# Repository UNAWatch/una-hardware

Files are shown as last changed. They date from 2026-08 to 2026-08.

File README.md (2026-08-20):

## Summary

This repo contains the hardware design files for UNA watch, enabling users to debug their own hardware. 

## Contents

una-watch

	- electronics
	
		Schematic, assembly and fabrication drawings for each of the 6 PCBs in UNA Watch:
	
		UNAaltimeter_MS5837
		UNAbody_PAH8316
		UNAcore
		UNAlink_AG3335M
		UNAlink_BLUENRG2
		UNAview_LS012
	
	- mechanical
	
		.stp files for each mechanical part

## License

The designs and related documentation
in this repository are licensed under the Creative Commons Attribution
4.0 International License (CC BY 4.0), unless otherwise noted.

You are free to use, reproduce, modify, manufacture from, and redistribute
these materials, provided appropriate attribution is given.

See the LICENSE file for details.

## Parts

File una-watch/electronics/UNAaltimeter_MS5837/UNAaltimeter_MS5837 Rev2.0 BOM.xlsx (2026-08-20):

Bill of Materials |  |  |  |  |  |  |  | Una Watch Ltd
PCB | UNAaltimeter_MS5837
BOM Revision | 2
Date | 2025-08-08
Author Email | lewis@unawatch.com
Item Number | Quantity | Value | Part Reference | Part_Number | Manufacturer | ManuPart | Description | PCB Footprint
1 | 1 | 470nF_6.3V | C5 | 001-0005 | Murata | GRM033R60J474KE90D | Cap ceramic,X5R,470nF,10%,6.3V,C0201 | C0201
2 | 1 | BM23PF0.8-10DP-0.35V51 | J1 | 200-0034 | Hirose | BM23PF0.8-10DP-0.35V51 | 10 position connector, plug, 0.35mm pitch, 0.3A signal contact, 5A power contact, 0.8mm stack height | HRS_BM23PF08-10DP-035V51
3 | 1 | MS583702BA01-50 | U3 | 103-0012 | TE | MS583702BA01-50 | Pressure and Temperature Sensor, Gel-filled | XDCR_MS583702BA01-50

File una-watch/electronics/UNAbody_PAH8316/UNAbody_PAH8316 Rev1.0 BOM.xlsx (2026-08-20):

Bill of Materials |  |  |  |  |  |  |  | Una Watch Ltd
PCB | UNAbody_PAH8316
BOM Revision | 1
Date | 2025-04-10
Author Email | lewis@unawatch.com
Item Number | Quantity | Value | Part Reference | Part_Number | Manufacturer | ManuPart | Description | PCB Footprint
1 | 6 | 1uF_10V | C1 C5 C10 C11 C13 C14 | 000-0003 | Murata | GRM155Z71A105KE01D | Cap ceramic,X7R,1uF,10%,10V,C0402 | C0402
2 | 6 | 100nF | C2 C3 C4 C6 C7 C12 | 001-0001 | Murata | GRM033R61A104KE15D | Cap ceramic,X5R,100nF,10%,10V,C0201 | C0201
3 | 2 | 22uF_10V | C8 C9 | 000-0002 | Murata | GRM158R61A226ME15D | Cap ceramic,X5R,22uF,20%,10V,C0402 | C0402
4 | 1 | 47nF | C15 | 001-0010 | Murata | GRM033R61C473KE84D | Cap ceramic,X5R,47nF,10%,16V,C0201 | C0201
5 | 4 | SFH_2703 | D1 D3 D4 D6 | 206-0005 | AMS OSRAM | SFH 2703 | Silicon PIN Photodiode, 0.95V Forward Voltage | C0603
6 | 2 | SFH_7016 | D2 D5 | 206-0006 | AMS OSRAM | SFH 7016 | Green, Red and Infrared LED, 1.85 x 1.65 package | C0603
7 | 1 | 330K_0201 | R1 | 011-0012 | Yageo | RC0201FR-07330KL | Resistor 330K 1% 0201 | R0201
8 | 1 | 82K_0201 | R2 | 011-0013 | Yageo | RC0201FR-0782KL | Resistor 82K 1% 0201 | R0201
9 | 34 | TP_1.0mm | TP1 TP2 TP3 TP4 TP5 TP6 TP7 TP8 TP9 TP10 TP11 TP12 TP13 TP14 TP15 TP16 TP17 TP18 TP19 TP20 TP21 TP22 TP23 TP24 TP25 TP26 TP27 TP28 TP29 TP30 TP31 TP32 TP33 TP34 | 202-0000 | N/A | N/A | NOPOP - SMT Test Point Circular 1.0 mm dia | TP_1-0mm_dia_SMT
10 | 1 | PAH8316LS-IN | U1 | 103-0010 | Pixart | PAH8316LS-IN | PPG AFE for HRD and SP02, 6 LED drivers, 4 Photodiode inputs, IR touch detection, DC Lead On/Off Detection
11 | 1 | NCP110AFCT180T2G | U2 | 101-0007 | OnSemi | NCP110AFCT180T2G | 1.8V Output LDO in WLCSP4 package, Input 1.1-5.5V, 200mA, PSRR: 95 dB,
12 | 1 | N24S64BC4DYT3G | U3 | 102-0002 | OnSemi | N24S64BC4DYT3G | EEPROM, 64Kb, I2C, CSP | BGA4C40P2X2_74X84X30
13 | 1 | NCP705MTADJTCG | U4 | 101-0009 | OnSemi | NCP705MTADJTCG | Adjustable Output LDO in WDFN5 package, Input 2.5-5.5V, 500mA, PSRR: 71 dB

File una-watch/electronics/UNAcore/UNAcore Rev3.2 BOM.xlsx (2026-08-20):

Bill of Materials |  |  |  |  |  |  |  | Una Watch Ltd
PCB | UNAcore
BOM Revision | 3.2
Date | 2026-05-05
Author Email | lewis@unawatch.com
Item Number | Quantity | Value | Part Reference | Part_Number | Manufacturer | ManuPart | Description | PCB Footprint
1 | 4 | 10uF_6.3V | C1 C13 C55 C57 | 000-0001 | Murata | GRM155R60J106ME15D | Cap ceramic,X5R,10uF,20%,6.3V,C0402 | C0402
2 | 27 | 100nF | C2 C3 C4 C5 C6 C7 C8 C9 C10 C11 C14 C16 C20 C21 C22 C23 C35 C36 C39 C40 C43 C44 C53 C62 C63 C80 C81 | 001-0001 | Murata | GRM033R61A104KE15D | Cap ceramic,X5R,100nF,10%,10V,C0201 | C0201
3 | 10 | 4.7uF_10V | C12 C37 C38 C48 C49 C50 C51 C58 C60 C66 | 000-0000 | TDK | C1005X5R1A475K050BC | Cap ceramic,X5R,4.7uF,10%,10V,C0402 | C0402
4 | 18 | 1.0uF_10V | C15 C17 C41 C42 C46 C54 C59 C71 C72 C73 C74 C76 C77 C78 C79 C84 C85 C87 | 001-0000 | Murata | GRM033R61A105ME15D | Cap ceramic,1.0uF,20%,10V,C0201 | C0201
5 | 5 | 2.2uF_10V | C18 C19 C45 C47 C89 | 001-0002 | Murata | GRM033R61A225KE47D | Cap ceramic,2.2uF,10%,10V,C0201 | C0201
6 | 2 | 470nF_6.3V | C52 C56 | 001-0005 | Murata | GRM033R60J474KE90D | Cap ceramic,X5R,470nF,10%,6.3V,C0201 | C0201
7 | 1 | 4.7nF | C61 | 001-0006 | Murata | GRM033R61A472KA01D | Cap ceramic,X5R, 4.7nF,10%,10V,C0201 | C0201
8 | 2 | 22uF_10V | C67 C68 | 000-0002 | Murata | GRM158R61A226ME15D | Cap ceramic,X5R,22uF,20%,10V,C0402 | C0402
9 | 2 | 8pF | C69 C70 | 001-0013 | Murata | GRM0335C1H8R0CA01D | Cap ceramic,C0G/NP0,8pF,+-0.25pF,50V,C0201 | C0201
10 | 1 | 2.2uF_50V_0603 | C86 | 002-0006 | Murata | GRM188R61H225KE11D | Cap ceramic,X5R, 2.2uF, 10%, 50V, C0603 | C0603
11 | 6 | RCLAMP2261ZA.F | D1 D2 D3 D4 D6 D7 | 206-0012 | Semtech | RCLAMP2261ZA.F | Bidirectional TVS ESD protection diode, 0201 package, 22V Working, 10.5V Clamp, 24V Breakdown, 30kV ESD | DIO_RCLAMP2261ZAF
12 | 1 | ESDA25P35-1U1M | D5 | 206-0011 | ST | ESDA25P35-1U1M | Unidirectional TVS ESD protection diode, 0603 package, 22V Working, 41V Clamp, 23.3V Breakdown, 30kV ESD | TVS_ESDA25P35-1U1M
13 | 2 | BM23PF0.8-24DS-0.35V51 | J1 J2 | 200-0027 | Hirose | BM23PF0.8-24DS-0.35V51 | 24 position connector, socket, 0.35mm pitch, 0.3A signal contact, 5A power contact, 0.8mm stack height | HRS_BM23PF08-24DS-035V51
14 | 1 | DF37NC1.5-30DS-0.4V | J3 | 200-0029 | Hirose | DF37NC1.5-30DS-0.4V | 30 position connector, receptacle, 0.4mm pitch, 0.3A current rating, 1.5mm stack height | HRS_DF37NC15-30DS-04V51
15 | 2 | A123803NXXSV072X01 | J4 J5 | 200-0016 | Tsingre | A123803NXXSV072X01 | Custom pogo pin connector, 8 pin, through-hole, 1.27mm pitch, 2 rows of 4 | TSINGRE_A123803NXXSV072X01
16 | 1 | CX90MWD2G-24P | J6 | 200-0028 | Hirose | CX90MWD2G-24P | USB Type-C connector, USB 3.1 Gen 2, 24 contact, mid mount, IPX8 | HIROSE_CX90MWD2G-24P
17 | 2 | SCTA4A0100 | J7 J8 | 200-0017 | Alps | SCTA4A0100 | Spring Contact, 1.4 x 1.4mm, 1.8m height uncompressed, 1.2-1.6mm compressed | ALPS_SCTA1A0100
18 | 1 | 9155002541006 | J9 | 200-0032 | Kyocera AVX | 9155002541006 | 2 Position Spring Battery Contact Connector Surface Mount, Right Angle | avx_9155002541006
19 | 1 | BM23PF0.8-10DS-0.35V51 | J10 | 200-0033 | Hirose | BM23PF0.8-10DS-0.35V51 | 10 position connector, socket, 0.35mm pitch, 0.3A signal contact, 5A power contact, 0.8mm stack height | HRS_BM23PF08-10DS-035V51
20 | 1 | M50-3630242 | J11 | 200-0031 | Harwin | M50-3630242 | 2 position header, pin strip, 1.27mm pitch, 3mm mating post length, SMT | HARWIN_M50-3630242
21 | 1 | una_shield_v2 | J12 | 203-0001 | Shenzhen Welin | una_shield_v2 | EMI shield for Una PCB V2 | una_shield_v2
22 | 3 | 2.2uH_750mA | L1 L2 L3 | 020-0000 | Murata | LQM18PN2R2MFR | Power Inductor 2.2uH, 375mOhm, 20%, Irating = 750mA,1.6 x 0.8 x 0.8mm | L0603
23 | 1 | 1uH_1.8A | L5 | 020-0001 | Murata | DFE18SBN1R0ME0L | Power Inductor 1uH, 120mOhm, 20%, Irating = 1.8A,1.6 x 0.8 x 0.8mm | L0603
24 | 1 | VZ30C1T8219732L | M1 | 205-0001 | Vybronics | VYBRONICS_VZ30C1T8219732L | Vibration ERM motor, 2.7V DC, 3.4mm Height | VYBRONICS_VZ30C1T8219732L
25 | 8 | 3K3_0201 | R1 R2 R3 R4 R5 R6 R7 R8 | 011-0002 | Yageo | RC0201FR-073K3L | Resistor 3K3 1% 0201 | R0201
26 | 2 | 10K_0201 | R9 R11 | 011-0000 | Yageo | RC0201JR-0710KL | Resistor 10K 5% 0201 | R0201
27 | 4 | 100K_0201 | R12 R13 R31 R37 | 011-0003 | Yageo | RC0201JR-07100KL | Resistor 100K 5% 0201 | R0201
28 | 7 | NOPOP | R24 R25 R27 R28 R29 R30 R39 | 011-0008 | NA | NA | Resistor NOPOP 0201 | R0201
29 | 1 | 0R0_0201 | R26 | 011-0005 | Yageo | RC0201FR-070RL | Resistor 0R0 1% 0201 | R0201
30 | 1 | 22K_0201 | R32 | 011-0016 | Yageo | RC0201FR-0722KL | Resistor 22K 1% 0201 | R0201
31 | 2 | 1K_0201 | R33 R34 | 011-0001 | Yageo | RC0201JR-071KL | Resistor 1K 5% 0201 | R0201
32 | 1 | 200R_0201 | R40 | 011-0009 | Yageo | RC0201FR-07200RL | Resistor 200R 1% 0201 | R0201
33 | 4 | EVPAEBB2A | SW1 SW2 SW3 SW4 | 201-0000 | Panasonic | EVPAEBB2A | Tactile switch, Edge-Mounted, Side Operated, 1.6N, 4.5 x 2.2mm | PANASONIC_EVPAEBB2A
34 | 36 | TP_1.0mm_dia_SMT | TP1 TP2 TP3 TP4 TP5 TP6 TP7 TP8 TP9 TP10 TP11 TP13 TP14 TP15 TP16 TP17 TP18 TP19 TP20 TP21 TP22 TP23 TP24 TP25 TP26 TP27 TP28 TP29 TP30 TP31 TP32 TP33 TP34 TP35 TP36 TP37 | 202-0000 | N/A | N/A | NOPOP - SMT Test Point Circular 1.0 mm dia | TP_1-0mm_dia_SMT
35 | 1 | STM32U5A5QJI6Q | U1 | 100-0003 | ST | STM32U5A5QJI6Q | 32-bit microcontroller, Cortex-M33, 160 MHz, 4MB Flash, 2.5MB RAM, with SMPS, UFBGA132 package, Hw Encryption | UFBGA132_7X7_STM
36 | 1 | SiT1532AC-J5-D14-32.768 | U2 | 106-0000 | SiTime | SiT1532AC-J5-D14-32.768 | 32.768 KHz mems oscillator, 75ppm, -10C to 70C | sit_csp4
37 | 2 | NCP335FCT2G | U3 U4 | 101-0006 | NXP | NCP335FCT2G | Load switch, 2A, WLCSP4 package | NCP334-D
38 | 1 | EMMC04G-CT32-01G10 | U5 | 102-0000 | Kingston | EMMC04G-CT32-01G10 | 4GB eMMC, Jedec eMMC 5.1 compliant, Ultra-small 7.5x9.0x0.8 | emmc_vfbfa153_7_5x9
39 | 1 | DRV2625YFF | U6 | 111-0000 | TI | DRV2625YFFR | Haptic driver for ERM/LRA with preloaded waveform data | BGA9C40P3X3_147X133X62
40 | 1 | PAM8904EGPR | U7 | 112-0000 | Diodes | PAM8904EGPR | Piezo sounder driver with charge pump boost converter | diodes_wqfn202012
41 | 1 | PCA9420UKZ | U8 | 101-0001 | NXP | PCA9420UKZ | PMIC with bat charger, 2 bucks, 2 LDOs | nxp_wlcsp25
42 | 1 | MAX17262REWL+ | U9 | 101-0002 | Maxim | MAX17262REWL+ | Battery Power Gauge IC, I2C Interface, Internal Current Sense Resistor | maxim_wlp9
43 | 1 | 74LVC1T45FW4-7 | U10 | 104-0000 | Diodes | 74LVC1T45FW4-7 | 1-bit level translator, direction control | di_x2-df1010-6
44 | 1 | TPS61299YBHR | U13 | 101-0003 | TI | TPS61299YBHR | Synchronous Boost Converter, Input 0.7-5.5V, Output 1.8-5.5V, WCSP package, Fast Transient Response | BGA6N40P3X2_122X88X62N
45 | 1 | AP7350D-30CF4-7 | U16 | 101-0008 | Diodes | AP7350D-30CF4-7 | Fixed 3.0V Output LDO in 4-XFBGA package, Input 2-5.25V, 150mA, 0.4uA quiescent current, with enable pin | AP7350D30CF47
46 | 1 | TXS0102DQMR | U17 | 104-0004 | TI | TXS0102DQMR | 2-bit level translator, bi-directional, open-drain and push-pull, X2SON package | IC_TXS0102DQMR
47 | 1 | STUSB4500LBJR | U18 | 104-0014 | ST | STUSB4500LBJR | USB Type-C Sink Port Controller, 5V Only | BGA25N40P5X5_259X259X54N
48 | 1 | STL4P3LLH6 | U19 | 113-0001 | ST | STL4P3LLH6 | P-channel MOSFET, -30V, -4A, RON=0.056, 2.4W, PowerFLAT 2x2 | STL4P3LLH6
49 | 2 | NX20P0407UKZ | U21 U22 | 104-0016 | NXP | NX20P0407UKZ | USB Type-C CC and SBU Protection with SBU Enable Pin | BGA12N40P3X4_127X167X56
50 | 1 | TPS7A0233PYCHR | U23 | 101-0013 | TI | TPS7A0233PYCHR | 3.3V Output LDO in DSBGA-4 package, Input 1.5V to 6.0V, 310mV dropout voltage, 200mA Output Current, 25nA Queiscent | BGA4C35P2X2_64X64X40
51 | 1 | Xtal_16Mhz | X1 | 105-0002 | ECS | ECS-160-8-37-CWY-TR3 | 16 MHz smd xtal, 15ppm, 8pF, 2mmx1.6mm, -30C to 85C | xtal_4pin_2x1p6

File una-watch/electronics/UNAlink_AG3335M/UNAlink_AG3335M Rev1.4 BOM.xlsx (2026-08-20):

Bill of Materials |  |  |  |  |  |  |  | Una Watch Ltd
PCB | UNAlink_AG3335M
BOM Revision | 1.4
Date | 2026-05-05
Author Email | lewis@unawatch.com
Item Number | Quantity | Value | Part Reference | Part_Number | Manufacturer | ManuPart | Description | PCB Footprint
1 | 8 | 100nF | C1 C8 C32 C36 C37 C38 C39 C40 | 001-0001 | Murata | GRM033R61A104KE15D | Cap ceramic,X5R,100nF,10%,10V,C0201 | C0201
2 | 7 | 2.2uF_10V | C2 C7 C18 C41 C43 C44 C45 | 001-0002 | Murata | GRM033R61A225KE47D | Cap ceramic,2.2uF,10%,10V,C0201 | C0201
3 | 14 | 1.0uF_10V | C3 C4 C6 C9 C10 C12 C13 C14 C20 C23 C24 C25 C26 C27 | 001-0000 | Murata | GRM033R61A105ME15D | Cap ceramic,1.0uF,20%,10V,C0201 | C0201
4 | 2 | 4.7uF_10V | C5 C21 | 000-0000 | TDK | C1005X5R1A475K050BC | Cap ceramic,X5R,4.7uF,10%,10V,C0402 | C0402
5 | 2 | 6pF | C19 C22 | 001-0012 | Murata | GRM0335C1H6R0CA01D | Cap ceramic,C0G/NP0,6pF,+-0.25pF,50V,C0201 | C0201
6 | 7 | 47pF | C28 C29 C30 C31 C33 C34 C35 | 001-0011 | Murata | GRM0335C1E470FA01D | Cap ceramic,C0G/NP0,47pF,1%,25V,C0201 | C0201
7 | 1 | 33pF | C42 | 001-0014 | Murata | GRM0335C1E330FA01D | Cap ceramic,C0G/NP0,33pF,1%,25V,C0201 | C0201
8 | 1 | NOPOP | D1 | 206-0013 | N/A | N/A | NOPOP - SP1005 Series | DIODFN60X30X33-2N
9 | 1 | SAFFB1G56KB0F0A | FL1 | 109-0000 | Murata | SAFFB1G56KB0F0A | GPS L1 Saw Filter | FIL_B39162B9417K610
10 | 1 | SAWFD1G17AA0F0A | FL2 | 109-0002 | Murata | SAWFD1G17AA0F0A | GPS L1 and L5 Saw Filter, 1 In, 2 Out | DS-SAWFD1G17AA0F0A
11 | 1 | SAFFB1G17AA0F0A | FL3 | 109-0001 | Murata | SAFFB1G17AA0F0A | GPS L5 Saw Filter | FIL_B39162B9417K610
12 | 1 | MP10363 | G1 | 106-0002 | Golledge | MP10363 | 26.0MHz GTXO-203T/ES SM TCXO 1.8V TCXO no VC, ±0.5ppm, -30+85°C 1.8V Supply | NT2016_SMALL
13 | 1 | BM23PF0.8-24DP-0.35V51 | J1 | 200-0026 | Hirose | BM23PF0.8-24DP-0.35V51 | 24 position connector, plug, 0.35mm pitch, 0.3A signal contact, 5A power contact, 0.8mm stack height | HRS_BM23PF08-24DP-035V51
14 | 3 | 3100069 | J2 J3 J4 | 200-0001 | TE | 3100069 | Spring Contact, 2.7 x 1.5mm, 1.7mm height uncompressed, 1.5A current | TE_3100069
15 | 1 | 8.2nH | L1 | 022-0006 | MURATA | LQP03HQ8N2H02D | RF Inductor, 8.2nH, 400mOhms, 3%, Irating = 300mA, 0201 | L0201
16 | 1 | NOPOP_0201 | L2 | 022-0011 | NA | NA | Inductor NOPOP 0201 | L0201
17 | 2 | 9.1nH | L3 L4 | 022-0005 | MURATA | LQP03HQ9N1H02D | RF Inductor, 9.1nH, 400mOhms, 3%, Irating = 300mA, 0201 | L0201
18 | 1 | 10nH | L5 | 022-0007 | MURATA | LQP03HQ10NH02D | RF Inductor, 10nH, 400mOhms, 3%, Irating = 300mA, 0201 | L0201
19 | 1 | 6.8nH | L6 | 022-0008 | MURATA | LQP03HQ6N8H02D | RF Inductor, 6.8nH, 400mOhms, 3%, Irating = 300mA, 0201 | L0201
20 | 1 | 6.2nH | L7 | 022-0009 | MURATA | LQP03HQ6N2H02D | RF Inductor, 6.2nH, 250mOhms, 3%, Irating = 400mA, 0201 | L0201
21 | 1 | 7.5nH | L8 | 022-0010 | MURATA | LQP03HQ7N5H02D | RF Inductor, 7.5nH, 300mOhms, 3%, Irating = 400mA, 0201 | L0201
22 | 1 | 4nH | L9 | 022-0004 | MURATA | LQP03TN4N0B02D | RF Inductor, 4nH, 400mOhms, 0.1nH, Irating = 350mA, 0201 | L0201
23 | 1 | 1nF | R3 | 001-0009 | Murata | GRM0335C1E102FA01D | Cap ceramic,C0G/NP0,1nF,1%,25V,C0201 | C0201
24 | 1 | 100K_0201 | R4 | 011-0003 | Yageo | RC0201JR-07100KL | Resistor 100K 5% 0201 | R0201
25 | 8 | NOPOP | R6 R7 R8 R10 R11 R13 R18 R19 | 011-0008 | NA | NA | Resistor NOPOP 0201 | R0201
26 | 3 | 0R0_0201 | R9 R16 R17 | 011-0005 | Yageo | RC0201FR-070RL | Resistor 0R0 1% 0201 | R0201
27 | 1 | 1K_0201 | R12 | 011-0001 | Yageo | RC0201JR-071KL | Resistor 1K 5% 0201 | R0201
28 | 1 | 33K_0201 | R14 | 011-0015 | Yageo | RC0201FR-0733KL | Resistor 33K 1% 0201 | R0201
29 | 1 | 82K_0201 | R15 | 011-0013 | Yageo | RC0201FR-0782KL | Resistor 82K 1% 0201 | R0201
30 | 7 | TP_1.0mm | TP6 TP7 TP8 TP9 TP11 TP12 TP16 | 202-0000 | N/A | N/A | NOPOP - SMT Test Point Circular 1.0 mm dia | TP_1-0mm_dia_SMT
31 | 1 | GND_PAD | TP15 | 208-0000 | N/A | N/A | Exposed ground pad for UNAlink | gnd_pad_x20_6_y2_5
32 | 1 | N24S64BC4DYT3G | U1 | 102-0002 | OnSemi | N24S64BC4DYT3G | EEPROM, 64Kb, I2C, CSP | BGA4C40P2X2_74X84X30
33 | 1 | AG3335MV/B | U2 | 103-0008 | Airoha | AG3335MV/B | Dual Frequency L1 L5 GNSS Receiver | AG3335M
34 | 1 | NCP335FCT2G | U3 | 101-0006 | NXP | NCP335FCT2G | Load switch, 2A, WLCSP4 package | NCP334-D
35 | 1 | BGA524N6 | U5 | 112-0001 | Infineon | BGA524N6E6327XTSA1 | GNSS L1 band low noise amplifier, 19.6 dB gain, 0.55 dB NF | PSON35P110X70X35-6N
36 | 1 | BGA855N6 | U6 | 112-0002 | Infineon | BGA855N6E6327XTSA1 | GNSS L2/L5 band low noise amplifier, 17.8 dB gain, 0.6 dB NF | PSON35P110X70X35-6N
37 | 1 | BMI270 | U7 | 103-0009 | Bosch | BMI270 | IMU 3D accelerometer, 3D gyroscope, SPI and I2C | ST_LGA-14
38 | 1 | BMM350 | U8 | 103-0011 | Bosch | BMM350 | 3-Axis Magnetic Sensor, I2C | BMM350
39 | 1 | LD57100JR | U9 | 101-0011 | ST | LD57100JR | Adjustable Output LDO, Vout = 0.5 to 3.0V, Vin = Vout + 40mV, Flipchip 6 package | BGA6C40P2X3_78X118X36
40 | 1 | ECS-.327-6-16R-TR | X1 | 105-0001 | ECS | ECS-.327-6-16R-TR | 32.768 KHz smd xtal, 20ppm, 6pF, 60kOhm ESR, 1.6mmx1.0mm, -40C to 85C | ECX-16R

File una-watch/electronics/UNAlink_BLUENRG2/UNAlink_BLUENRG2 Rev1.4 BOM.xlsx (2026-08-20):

Bill of Materials |  |  |  |  |  |  |  | Una Watch Ltd
PCB | UNAlink_BLUENRG2
BOM Revision | 1.4
Date | 2026-02-05
Author Email | lewis@unawatch.com
Item Number | Quantity | Value | Part Reference | Part_Number | Manufacturer | ManuPart | Description | PCB Footprint
1 | 3 | 1.0uF_10V | C1 C3 C11 | 001-0000 | Murata | GRM033R61A105ME15D | Cap ceramic,1.0uF,20%,10V,C0201 | C0201
2 | 6 | 100nF | C2 C4 C5 C7 C10 C12 | 001-0001 | Murata | GRM033R61A104KE15D | Cap ceramic,X5R,100nF,10%,10V,C0201 | C0201
3 | 1 | 150pF | C6 | 001-0003 | Murata | GRM033R71C151KA01D | Cap ceramic,X7R,150pF,10%,16V,C0201 | C0201
4 | 2 | 12pF | C8 C9 | 001-0004 | Murata | GRM0335C1H120GA01D | Cap ceramic,C0G/NP0,12pF,2%,50V,C0201 | C0201
5 | 1 | BM23PF0.8-24DP-0.35V51 | J1 | 200-0026 | Hirose | BM23PF0.8-24DP-0.35V51 | 24 position connector, plug, 0.35mm pitch, 0.3A signal contact, 5A power contact, 0.8mm stack height | HRS_BM23PF08-24DP-035V51
6 | 2 | 3100069 | J2 J3 | 200-0001 | TE | 3100069 | Spring Contact, 2.7 x 1.5mm, 1.7mm height uncompressed, 1.5A current | TE_3100069
7 | 2 | 10K_0201 | R1 R5 | 011-0000 | Yageo | RC0201JR-0710KL | Resistor 10K 5% 0201 | R0201
8 | 2 | 1K_0201 | R2 R3 | 011-0001 | Yageo | RC0201JR-071KL | Resistor 1K 5% 0201 | R0201
9 | 2 | NOPOP_0201 | R4 R6 | 011-0008 | NA | NA | Resistor NOPOP 0201 | R0201
10 | 2 | 0R0_0201 | R7 R8 | 011-0005 | Yageo | RC0201FR-070RL | Resistor 0R0 1% 0201 | R0201
11 | 8 | TP_1.0mm | TP1 TP2 TP3 TP4 TP8 TP9 TP10 TP13 | 202-0000 | N/A | N/A | NOPOP - SMT Test Point Circular 1.0 mm dia | TP_1-0mm_dia_SMT
12 | 1 | GND_PAD | TP14 | 208-0000 | N/A | N/A | Exposed ground pad for UNAlink | gnd_pad_x20_6_y2_5
13 | 1 | BlueNRG-234N | U1 | 100-0001 | ST | BlueNRG-234N | Bluetooth low energy network coprocessor, BLE 5.0 compliant | ST_WLCSP34
14 | 1 | BALF-NRG-02D3 | U2 | 107-0000 | ST | BALF-NRG-02D3 | Matching network and harmonic filter for ST BlueNRG | ST_WLCSP4
15 | 1 | N24S64BC4DYT3G | U3 | 102-0002 | OnSemi | N24S64BC4DYT3G | EEPROM, 64Kb, I2C, CSP | BGA4C40P2X2_74X84X30
16 | 1 | Xtal_32Mhz | X1 | 105-0000 | Murata | XRCGB32M000F2P00R0 | 32 MHz smd xtal, 20ppm, 6pF, 2mmx1.6mm, -30C to 85C | xtal_4pin_2x1p6

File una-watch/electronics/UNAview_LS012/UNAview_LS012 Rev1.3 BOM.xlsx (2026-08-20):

Bill of Materials |  |  |  |  |  |  |  | Una Watch Ltd
PCB | UNAview_LS012
BOM Revision | 1.3
Date | 2025-04-09
Author Email | lewis@unawatch.com
Item Number | Quantity | Value | Part Reference | Part_Number | Manufacturer | ManuPart | Description | PCB Footprint
1 | 7 | 100nF | C1 C2 C3 C5 C6 C7 C8 | 001-0001 | Murata | GRM033R61A104KE15D | Cap ceramic,X5R,100nF,10%,10V,C0201 | C0201
2 | 3 | 1.0uF_10V | C4 C9 C10 | 001-0000 | Murata | GRM033R61A105ME15D | Cap ceramic,1.0uF,20%,10V,C0201 | C0201
3 | 1 | DF37C-30DP-0.4V | J1 | 200-0030 | Hirose | DF37C-30DP-0.4V | 30 position connector, plug, 0.4mm pitch, 0.3A current rating, 1.5mm stack height | HRS_DF37C-30DP-04V51_l3
4 | 1 | 503566-2102 | J2 | 200-0000 | Molex | 503566-2102 | 0.30mm Pitch Easy-On FPC Connector, 0.95mm Height, Right Angle, Surface Mount, Bottom Contact Style, 21 Circuits | MOLEX_5035662102
5 | 1 | 503480-0400 | J3 | 200-0020 | Molex | 503480-0400 | 0.50mm Pitch Easy-On BackFlip Type FPC Connector, 1.00mm Height, Right Angle, Surface Mount, Dual Contact Style, 4 Circuits | MOLEX_503480-0400
6 | 1 | NTK3139PT1G | Q1 | 113-0000 | On Semi | NTK3139PT1G | P-channel MOSFET, -20V, -780mA, RON=0.38, 310mW, SOT723 | ONSEMI_SOT723
7 | 1 | 10K_0201 | R1 | 011-0000 | Yageo | RC0201JR-0710KL | Resistor 10K 5% 0201 | R0201
8 | 1 | 82R_0201 | R2 | 011-0010 | Yageo | RC0201FR-0782RL | Resistor 82R 1% 0201 | R0201
9 | 17 | TP_1.0mm_dia_SMT | TP1 TP2 TP3 TP4 TP5 TP6 TP7 TP8 TP9 TP10 TP11 TP12 TP13 TP14 TP15 TP16 TP17 | 202-0000 | N/A | N/A | NOPOP - SMT Test Point Circular 1.0 mm dia | TP_1-0mm_dia_SMT
10 | 2 | TXB0108YZPR | U1 U2 | 104-0001 | TI | TXB0108YZPR | 8-bit level translator, auto-direction sensing, bi-directional, push-pull, DSBGA package | BGA20N50P4X5_188X238X50
11 | 1 | N24S64BC4DYT3G | U4 | 102-0002 | OnSemi | N24S64BC4DYT3G | EEPROM, 64Kb, I2C, CSP | BGA4C40P2X2_74X84X30

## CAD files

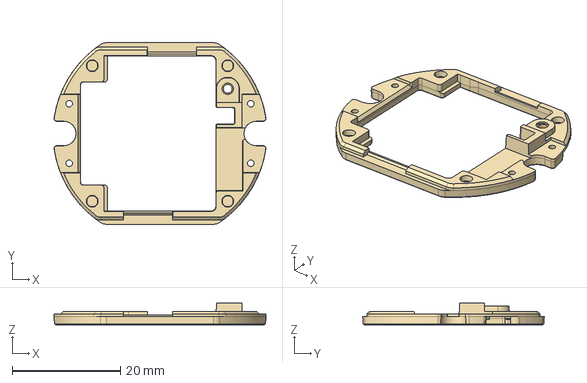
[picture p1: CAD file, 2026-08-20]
una-watch/mechanical/Battery_Compartment_501-0018_Rev-2.stp
39.1 x 33.5 x 4.00 mm

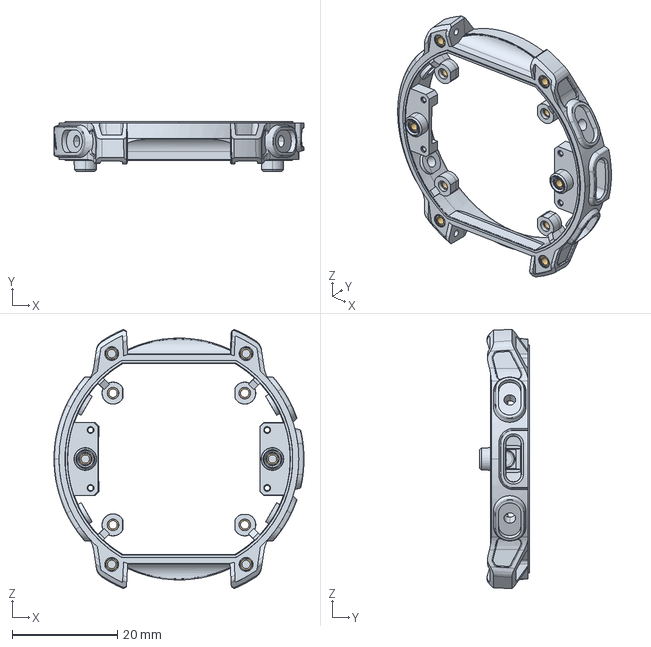
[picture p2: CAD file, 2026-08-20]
una-watch/mechanical/Housing_501-0015_Rev-2.stp
47.4 x 9.40 x 49.2 mm

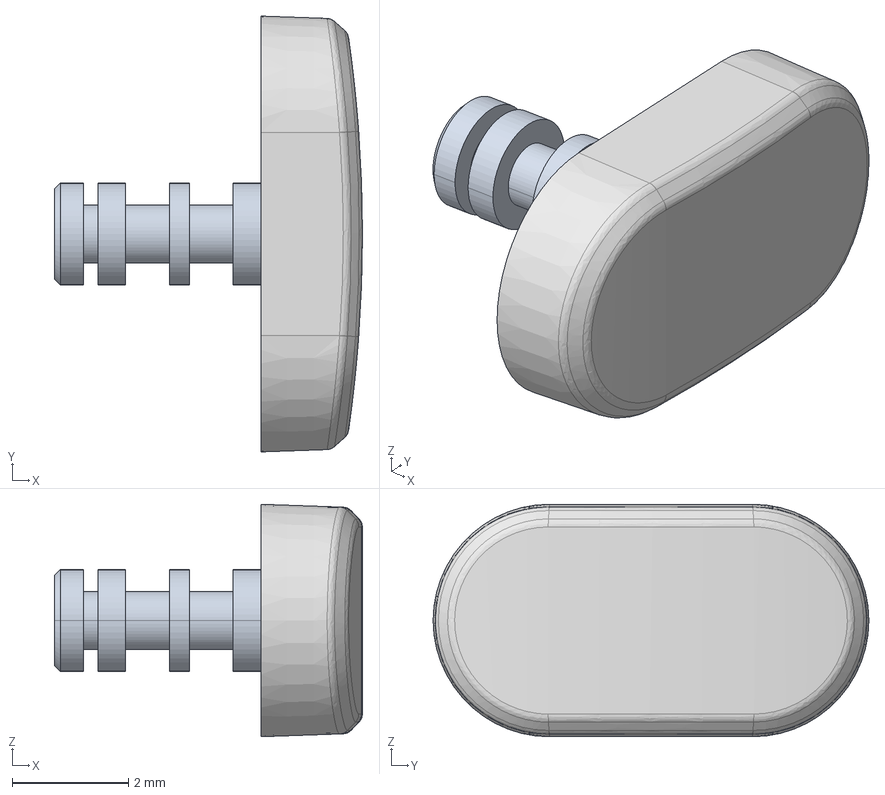
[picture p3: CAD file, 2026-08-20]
una-watch/mechanical/Button_400-0015_Rev-3.stp
5.30 x 7.50 x 4.00 mm

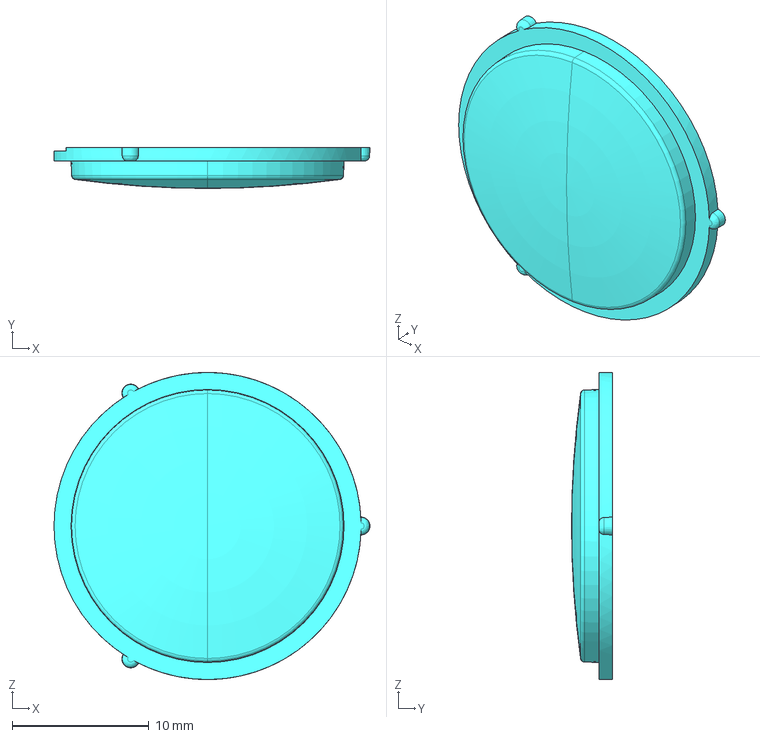
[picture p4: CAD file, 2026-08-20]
una-watch/mechanical/Rear_Cover_Dome_501-0023_Rev-1.stp
23.2 x 3.00 x 22.5 mm
501-0019-DOME-2-SKIN
501-0019-DOME-2

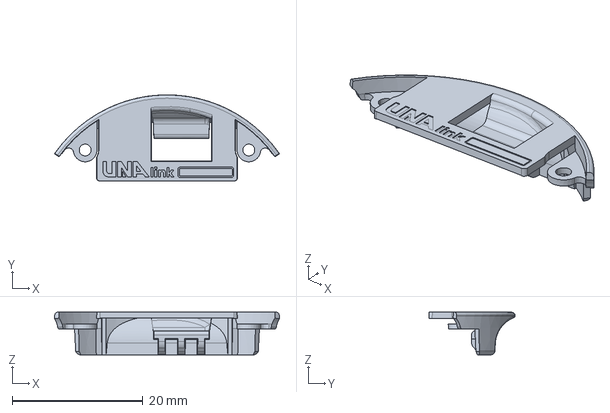
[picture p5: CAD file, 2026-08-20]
una-watch/mechanical/Antenna_501-0017_Rev-8.stp
34.4 x 13.2 x 6.50 mm

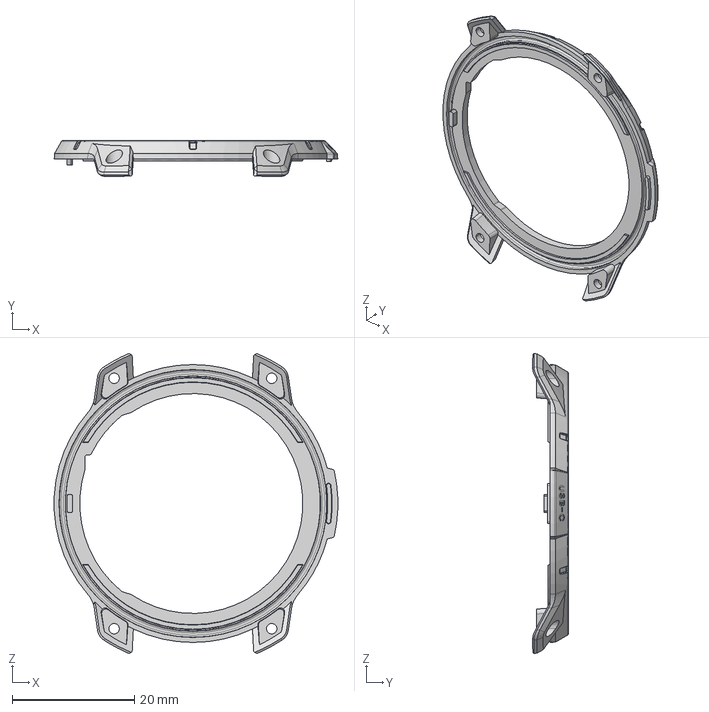
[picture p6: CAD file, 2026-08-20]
una-watch/mechanical/Bezel_501-0016_Rev-2.stp
46.4 x 5.84 x 49.1 mm

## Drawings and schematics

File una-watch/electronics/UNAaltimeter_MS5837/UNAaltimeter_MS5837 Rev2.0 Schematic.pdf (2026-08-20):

# 01 - Summary

Usage: | Altimeter PCB for UNA Watch

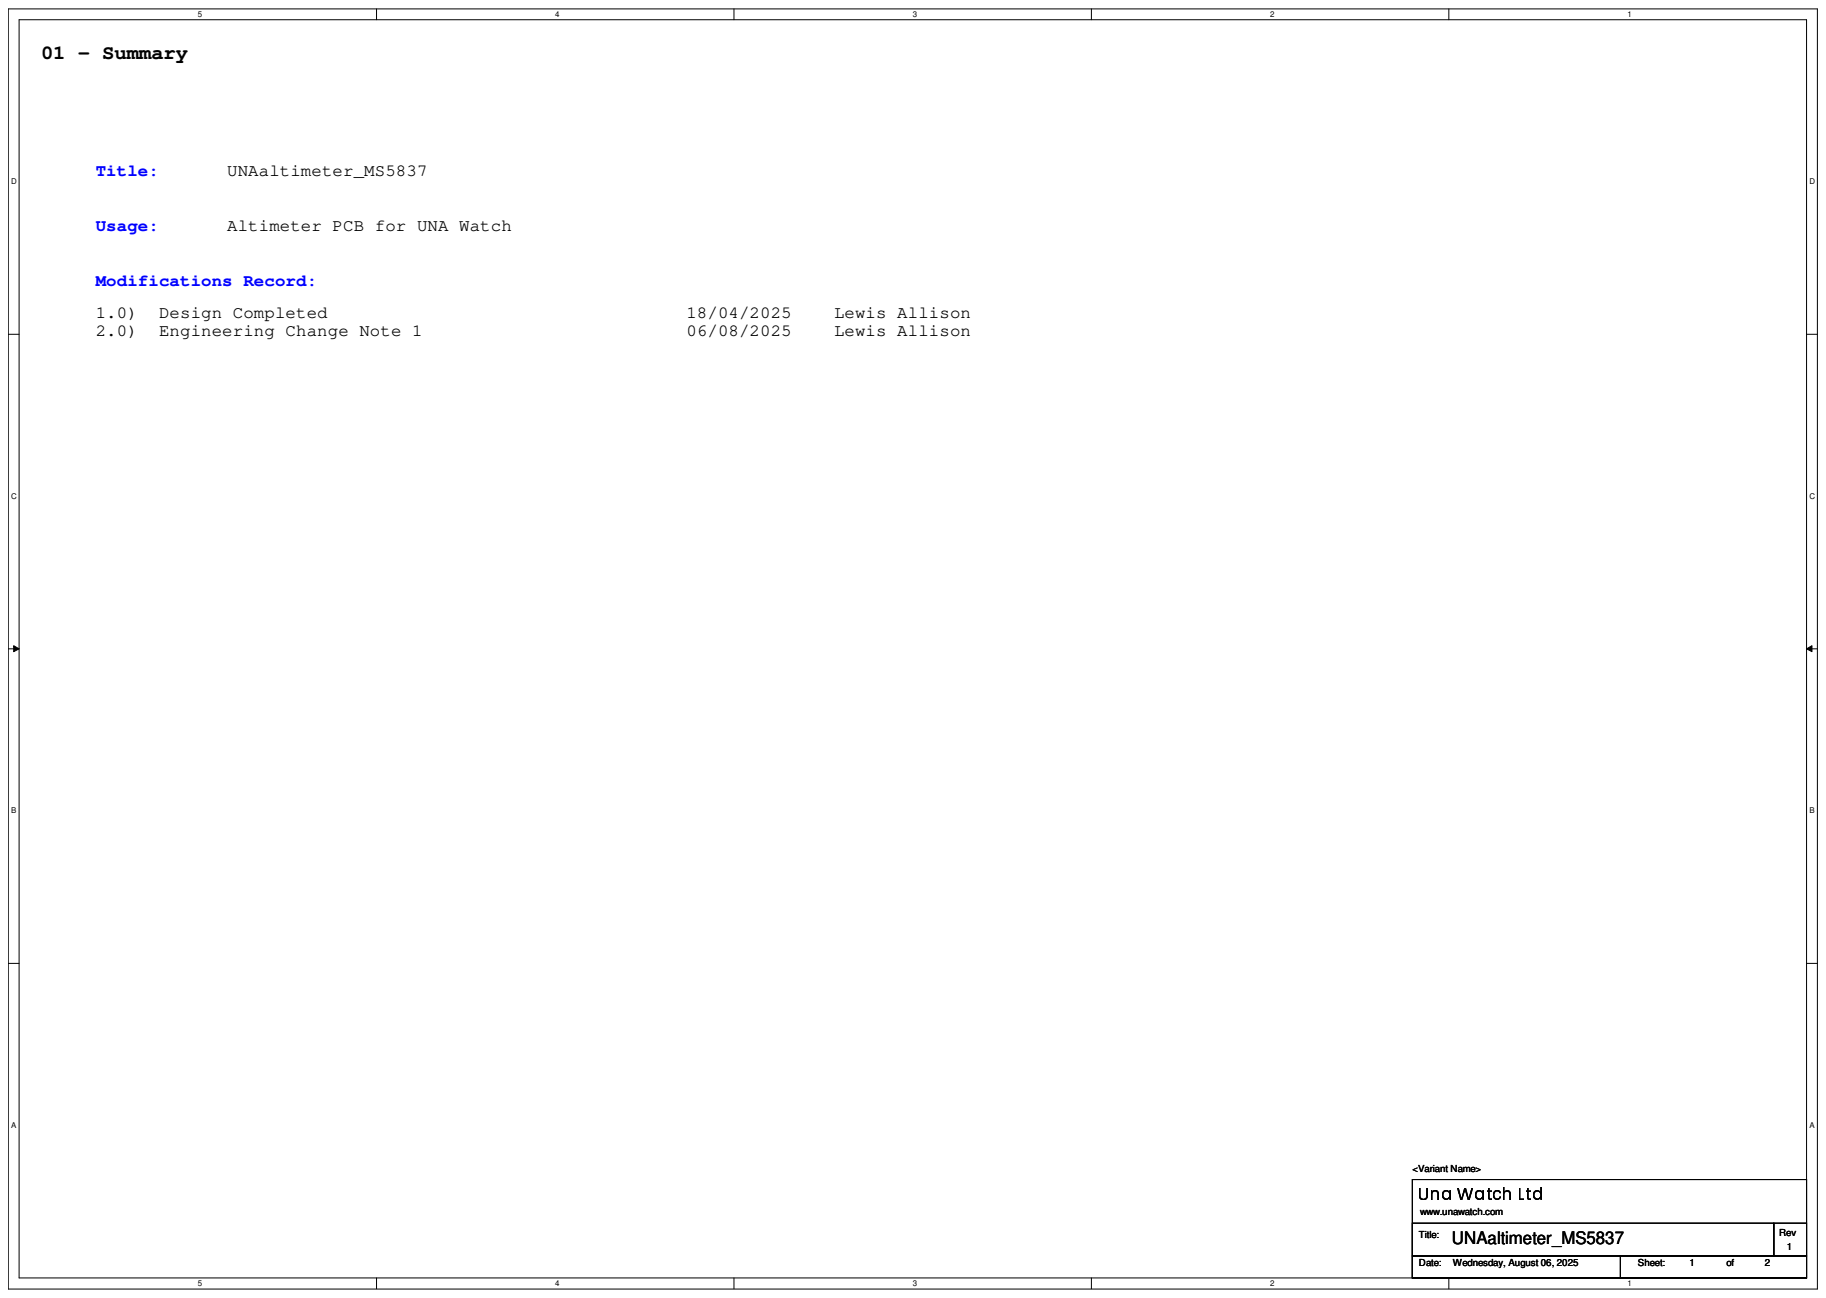
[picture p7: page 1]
Modifications Record:; Title:; UNAaltimeter_MS5837; Design Completed; Lewis Allison; Engineering Change Note 1; Rev; Date:; Sheet:; 1 2Wednesday, August 06, 2025; <Variant Name>

www.unawatch.com

# 02 - Altimeter

Main Board Interface | Digital Pressure and Altimeter Sensor

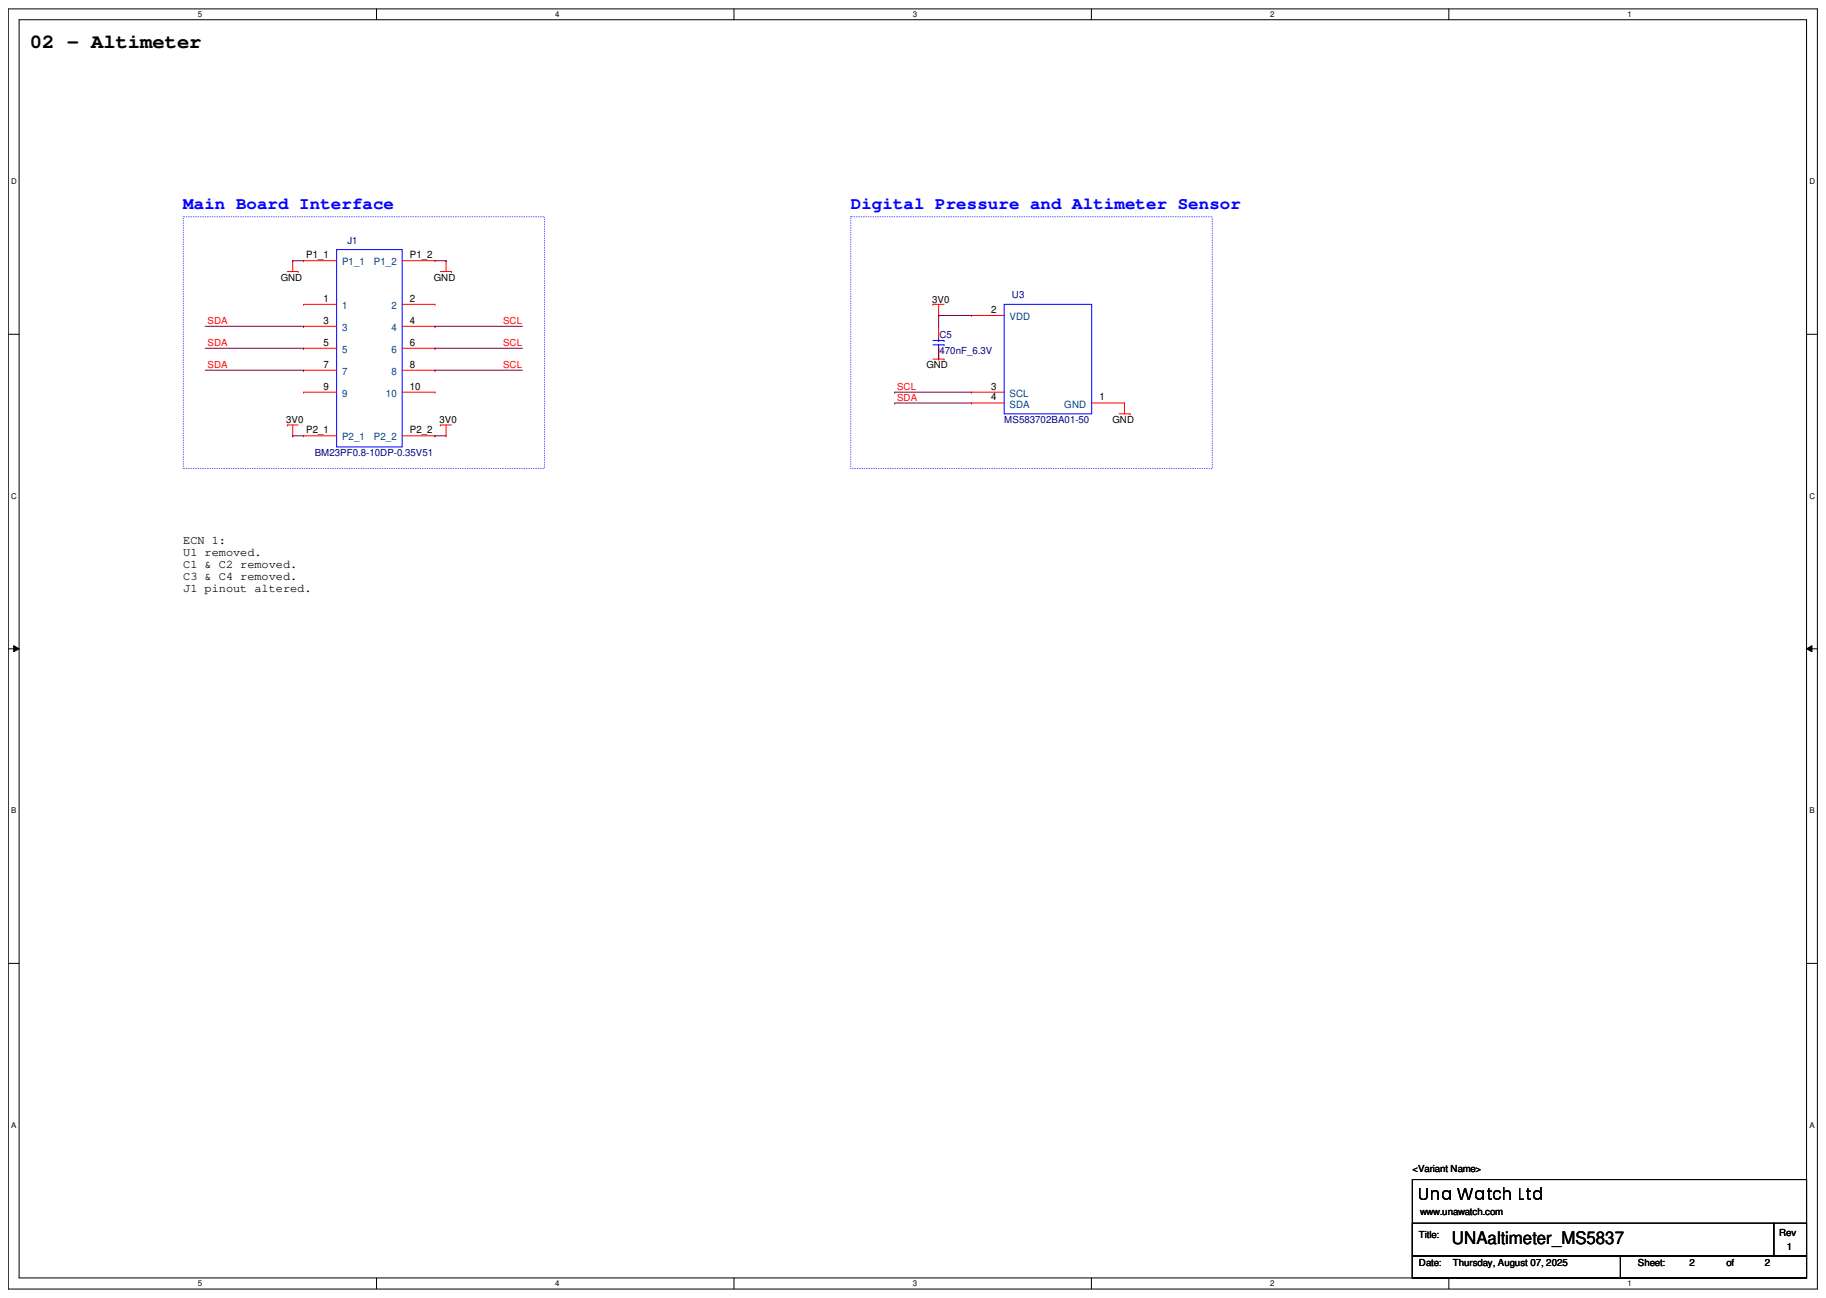
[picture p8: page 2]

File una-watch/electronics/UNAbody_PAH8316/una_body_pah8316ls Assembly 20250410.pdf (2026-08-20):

| REVISIONS

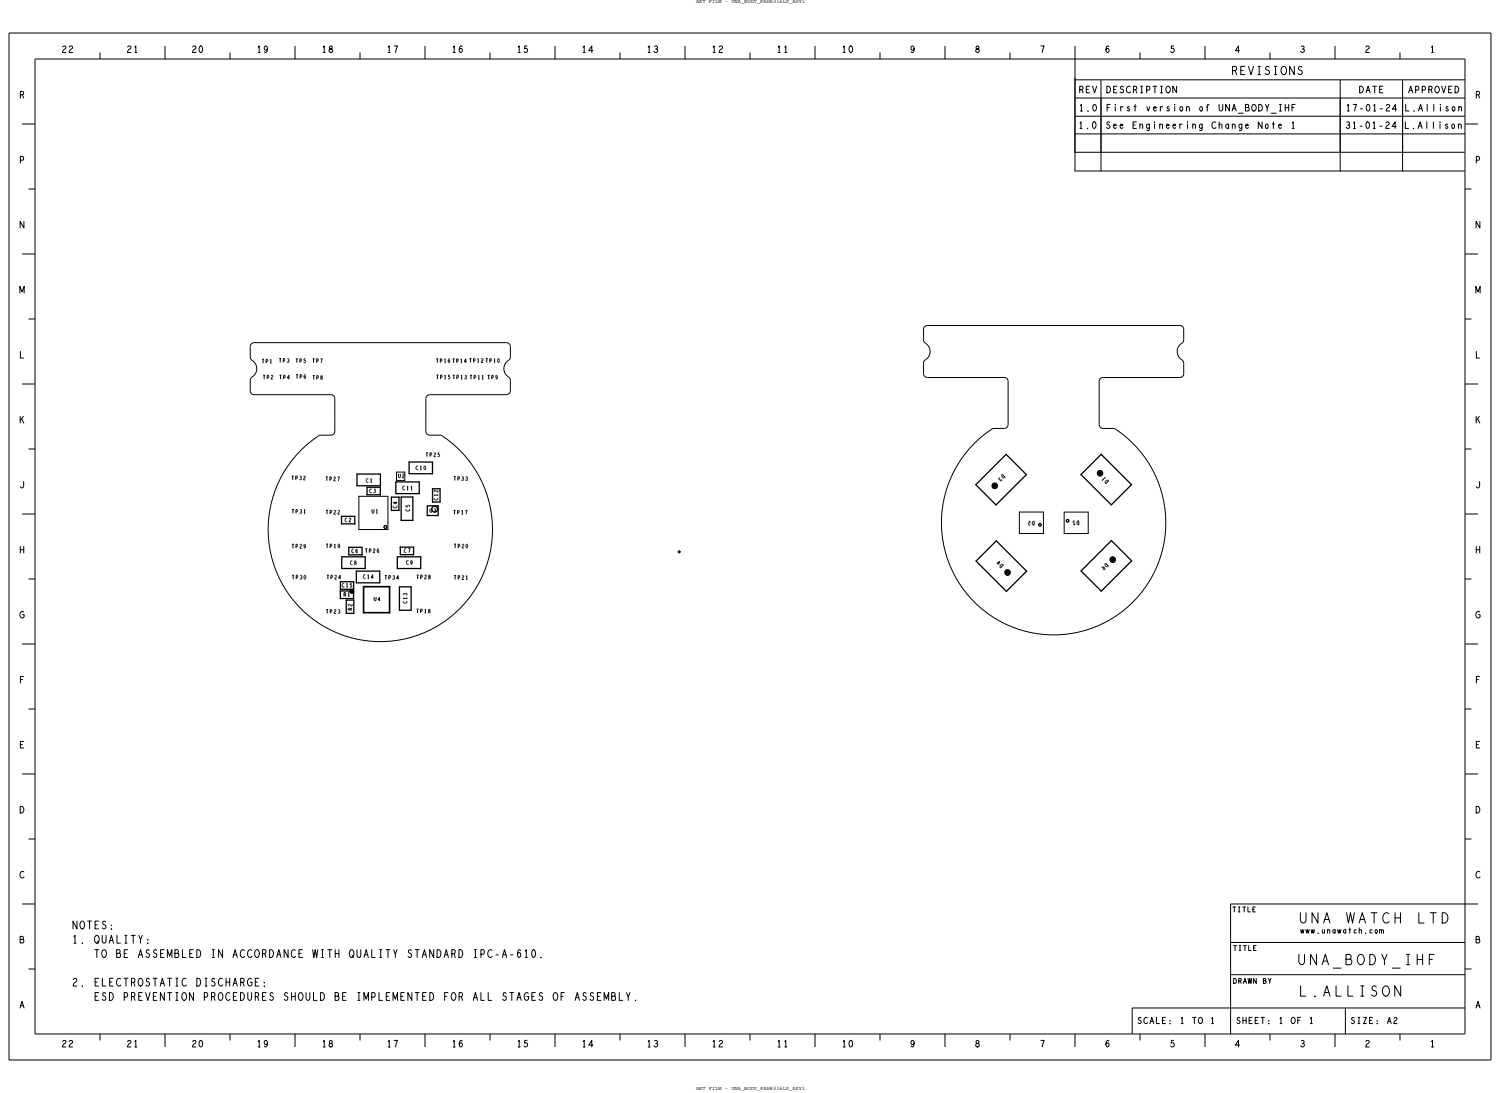
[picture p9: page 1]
ART FILM - UNA_BODY_PAH8316LS_ASY1; TITLE; 1. QUALITY:; NOTES:; TO BE ASSEMBLED IN ACCORDANCE WITH QUALITY STANDARD; IPC-A-610.; 2. ELECTROSTATIC DISCHARGE:; ESD PREVENTION PROCEDURES SHOULD BE; IMPLEMENTED FOR ALL STAGES OF ASSEMBLY.

REV | DESCRIPTION | DATE | APPROVED
1.0 | First version of UNA_BODY_IHF | | | 17-01-24 | L.Allison
1.0 | See Engineering Change Note 1 | | | | 31-01-24 | L.Allison

UNA WATCH LTD
www.unawatch.com

TITLE UNA_BODY_IHF
DRAWN BY L.ALLISON

SCALE: 1 TO 1 | SHEET: 1 OF 1 | SIZE: A2

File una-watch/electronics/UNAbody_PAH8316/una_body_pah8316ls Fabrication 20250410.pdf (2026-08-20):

## BASIC SPECIFICATION

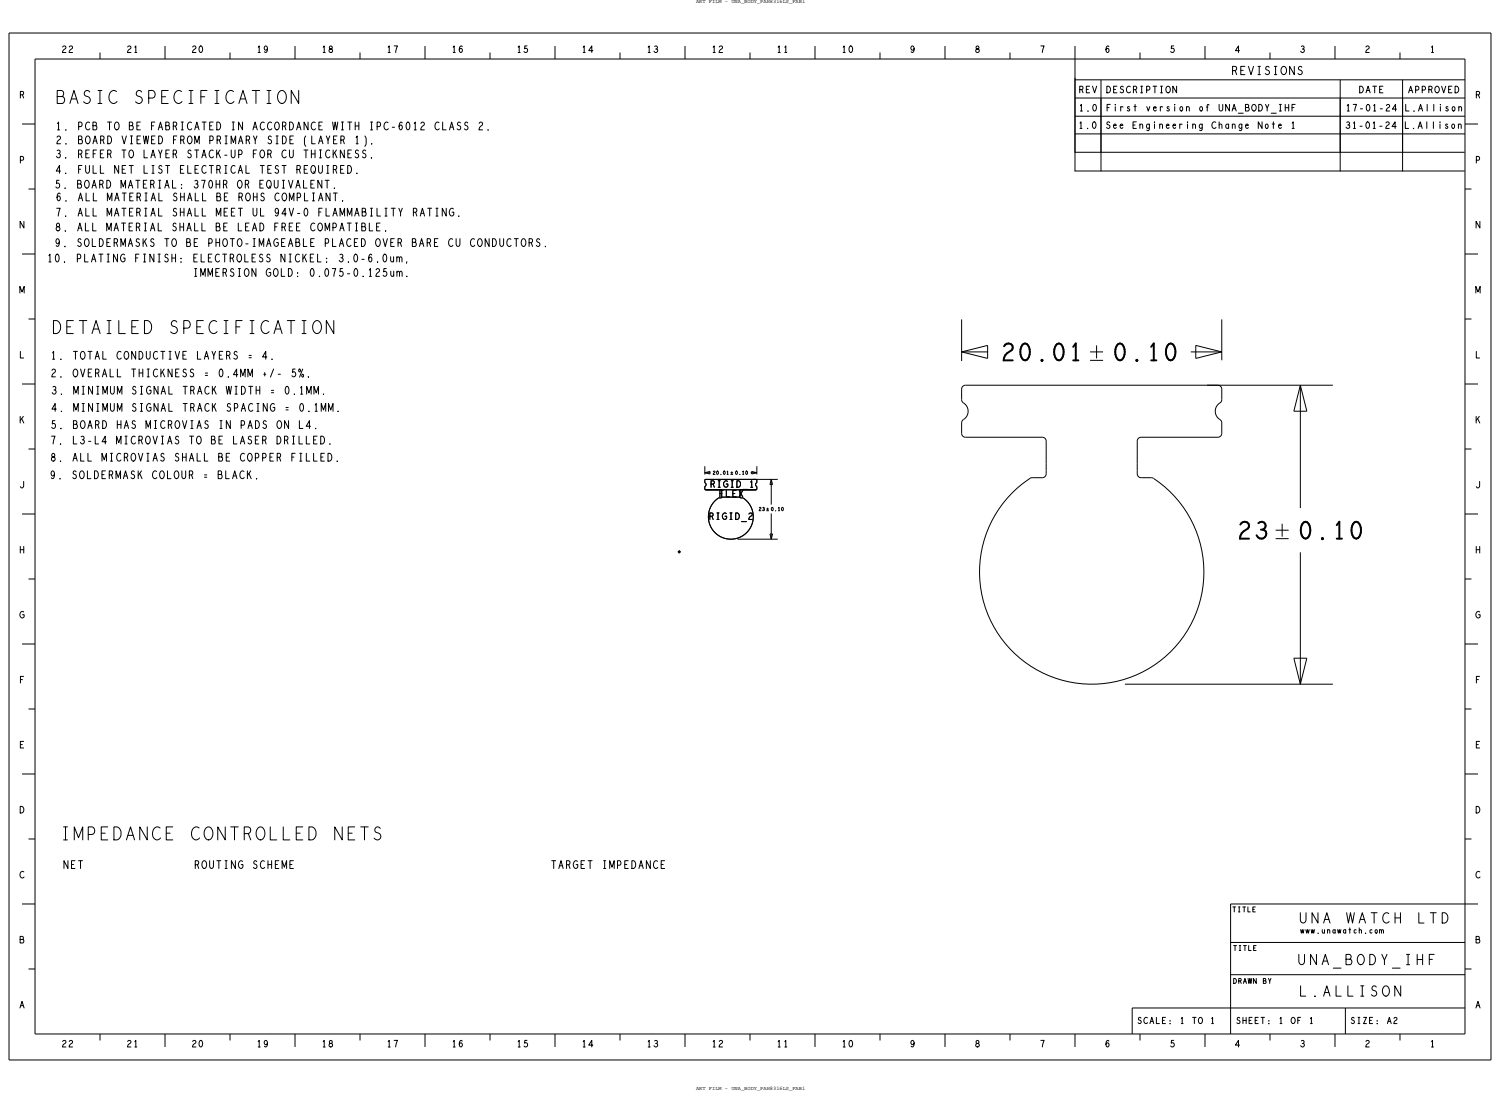
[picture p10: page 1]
ART FILM - UNA_BODY_PAH8316LS_FAB1; FLEX; RIGID_1; RIGID_2; TITLE; 1. PCB TO BE FABRICATED; IN ACCORDANCE WITH; IPC-6012 CLASS 2.; DETAILED SPECIFICATION; 5. BOARD; HAS MICROVIAS IN PADS ON L4.; NET; ROUTING SCHEME; TARGET; IMPEDANCE; IMMERSION GOLD: 0.075-0.125um.

8. ALL MATERIAL SHALL BE LEAD FREE COMPATIBLE. 2. OVERALL THICKNESS = 0.4MM +/- 5%. | REVISIONS

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

2. BOARD VIEWED FROM PRIMARY SIDE (LAYER 1).
3. REFER TO LAYER STACK-UP FOR CU THICKNESS.
4. FULL NET LIST ELECTRICAL TEST REQUIRED.
5. BOARD MATERIAL: 370HR OR EQUIVALENT.
6. ALL MATERIAL SHALL BE ROHS COMPLIANT.
7. ALL MATERIAL SHALL MEET UL 94V-0 FLAMMABILITY RATING.

9. SOLDERMASKS TO BE PHOTO-IMAGEABLE PLACED OVER BARE CU CONDUCTORS.
10. PLATING FINISH: ELECTROLESS NICKEL: 3.0-6.0um,

1. TOTAL CONDUCTIVE LAYERS = 4.

3. MINIMUM SIGNAL TRACK WIDTH = 0.1MM.
4. MINIMUM SIGNAL TRACK SPACING = 0.1MM.
7. L3-L4 MICROVIAS TO BE LASER DRILLED.
8. ALL MICROVIAS SHALL BE COPPER FILLED.
9. SOLDERMASK COLOUR = BLACK.

IMPEDANCE CONTROLLED NETS

UNA WATCH LTD
www.unawatch.com

TITLE UNA_BODY_IHF
DRAWN BY L.ALLISON

SCALE: 1 TO 1 | SHEET: 1 OF 1 | SIZE: A2

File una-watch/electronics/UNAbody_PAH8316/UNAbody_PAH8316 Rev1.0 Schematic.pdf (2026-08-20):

# 01 - Summary

Usage: | Body Sensor PCB for Una Watch with PAH8316LS PPG Sensor

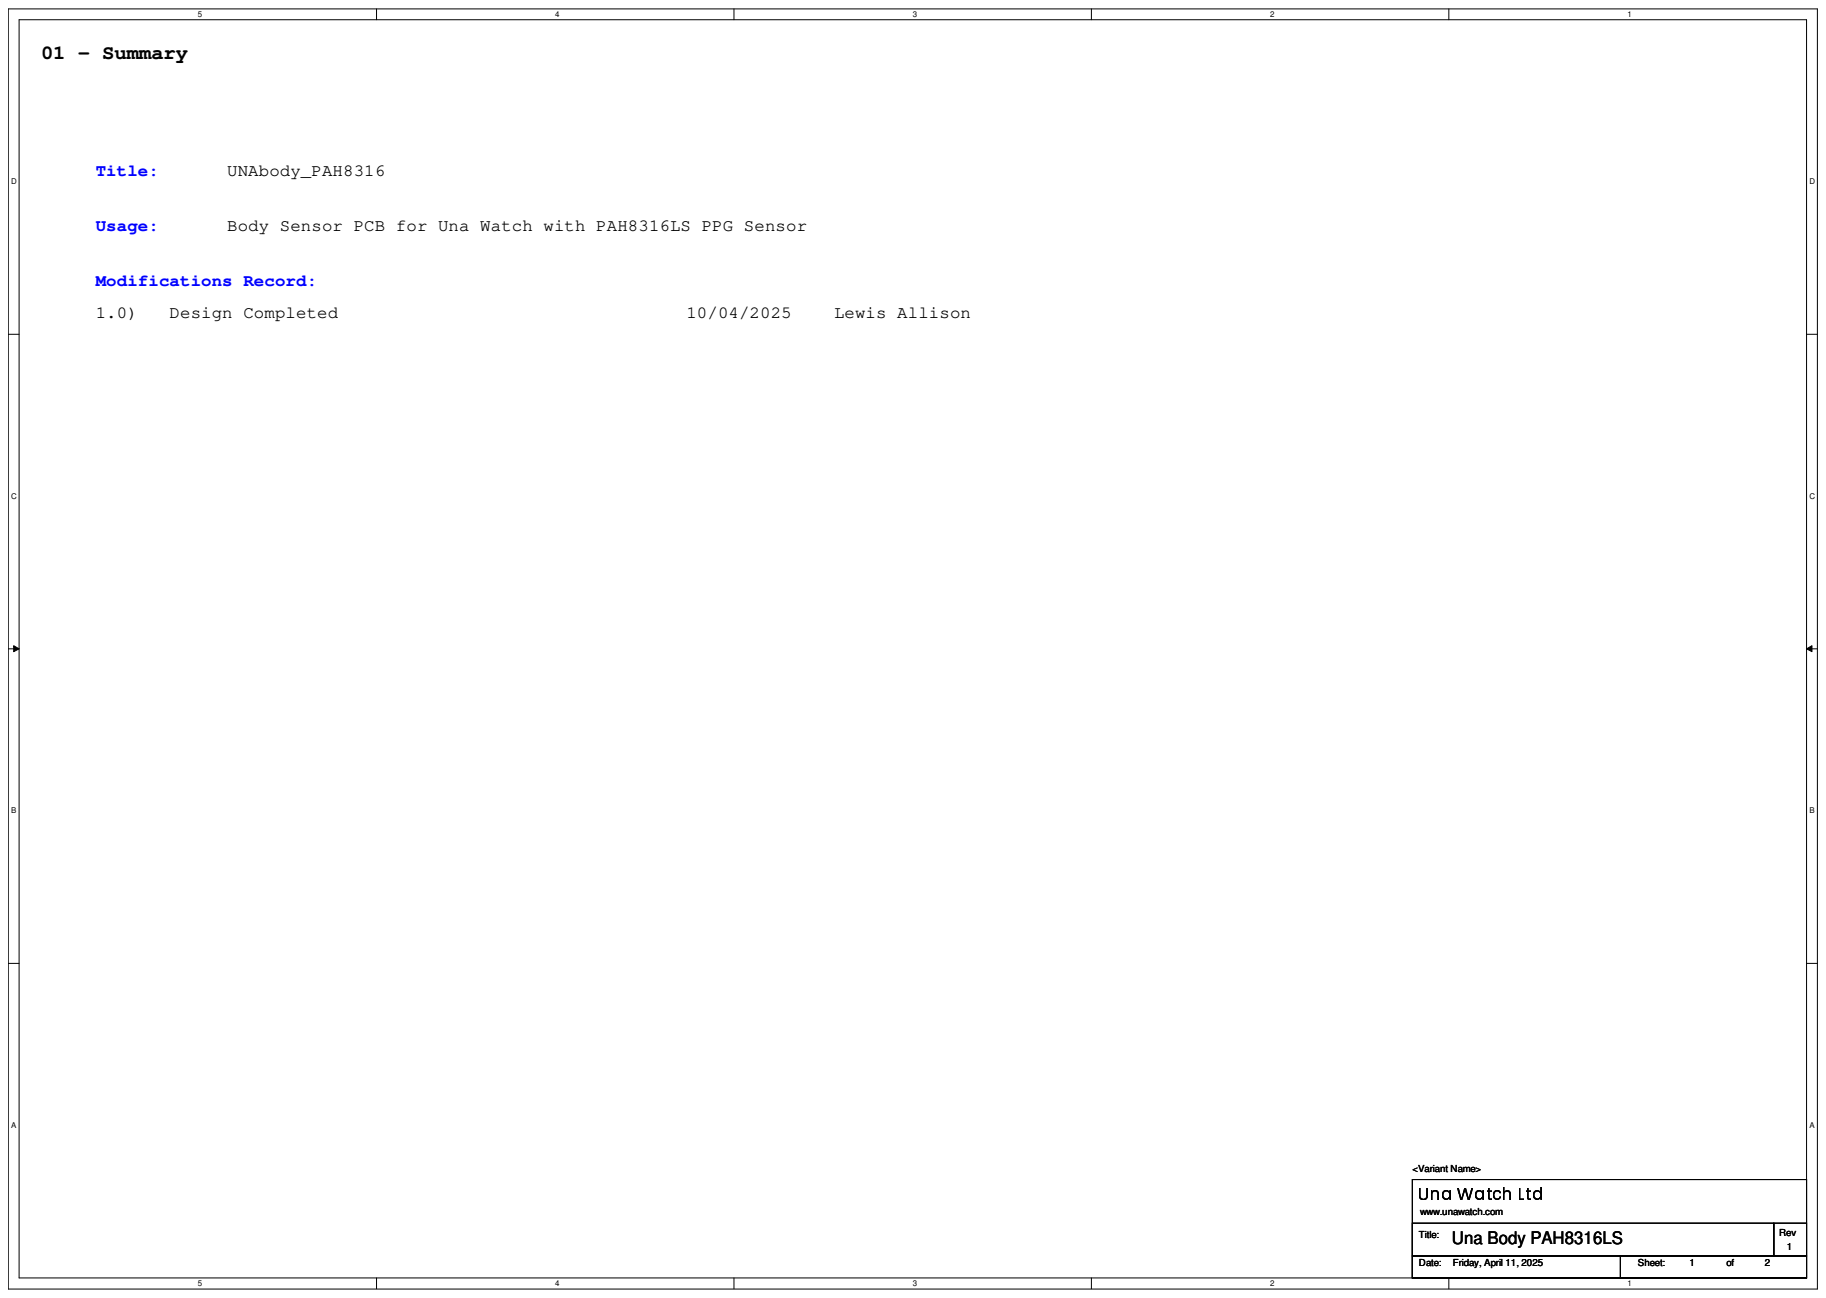
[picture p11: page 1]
Modifications Record:; Title:; UNAbody_PAH8316; Design Completed; Lewis Allison; Rev; Date:; Sheet:; Una Body PAH8316LS; 2Friday, April 11, 2025; <Variant Name>

www.unawatch.com

# 02 - PPG Sensor

Main Board Interface | PPG AFE

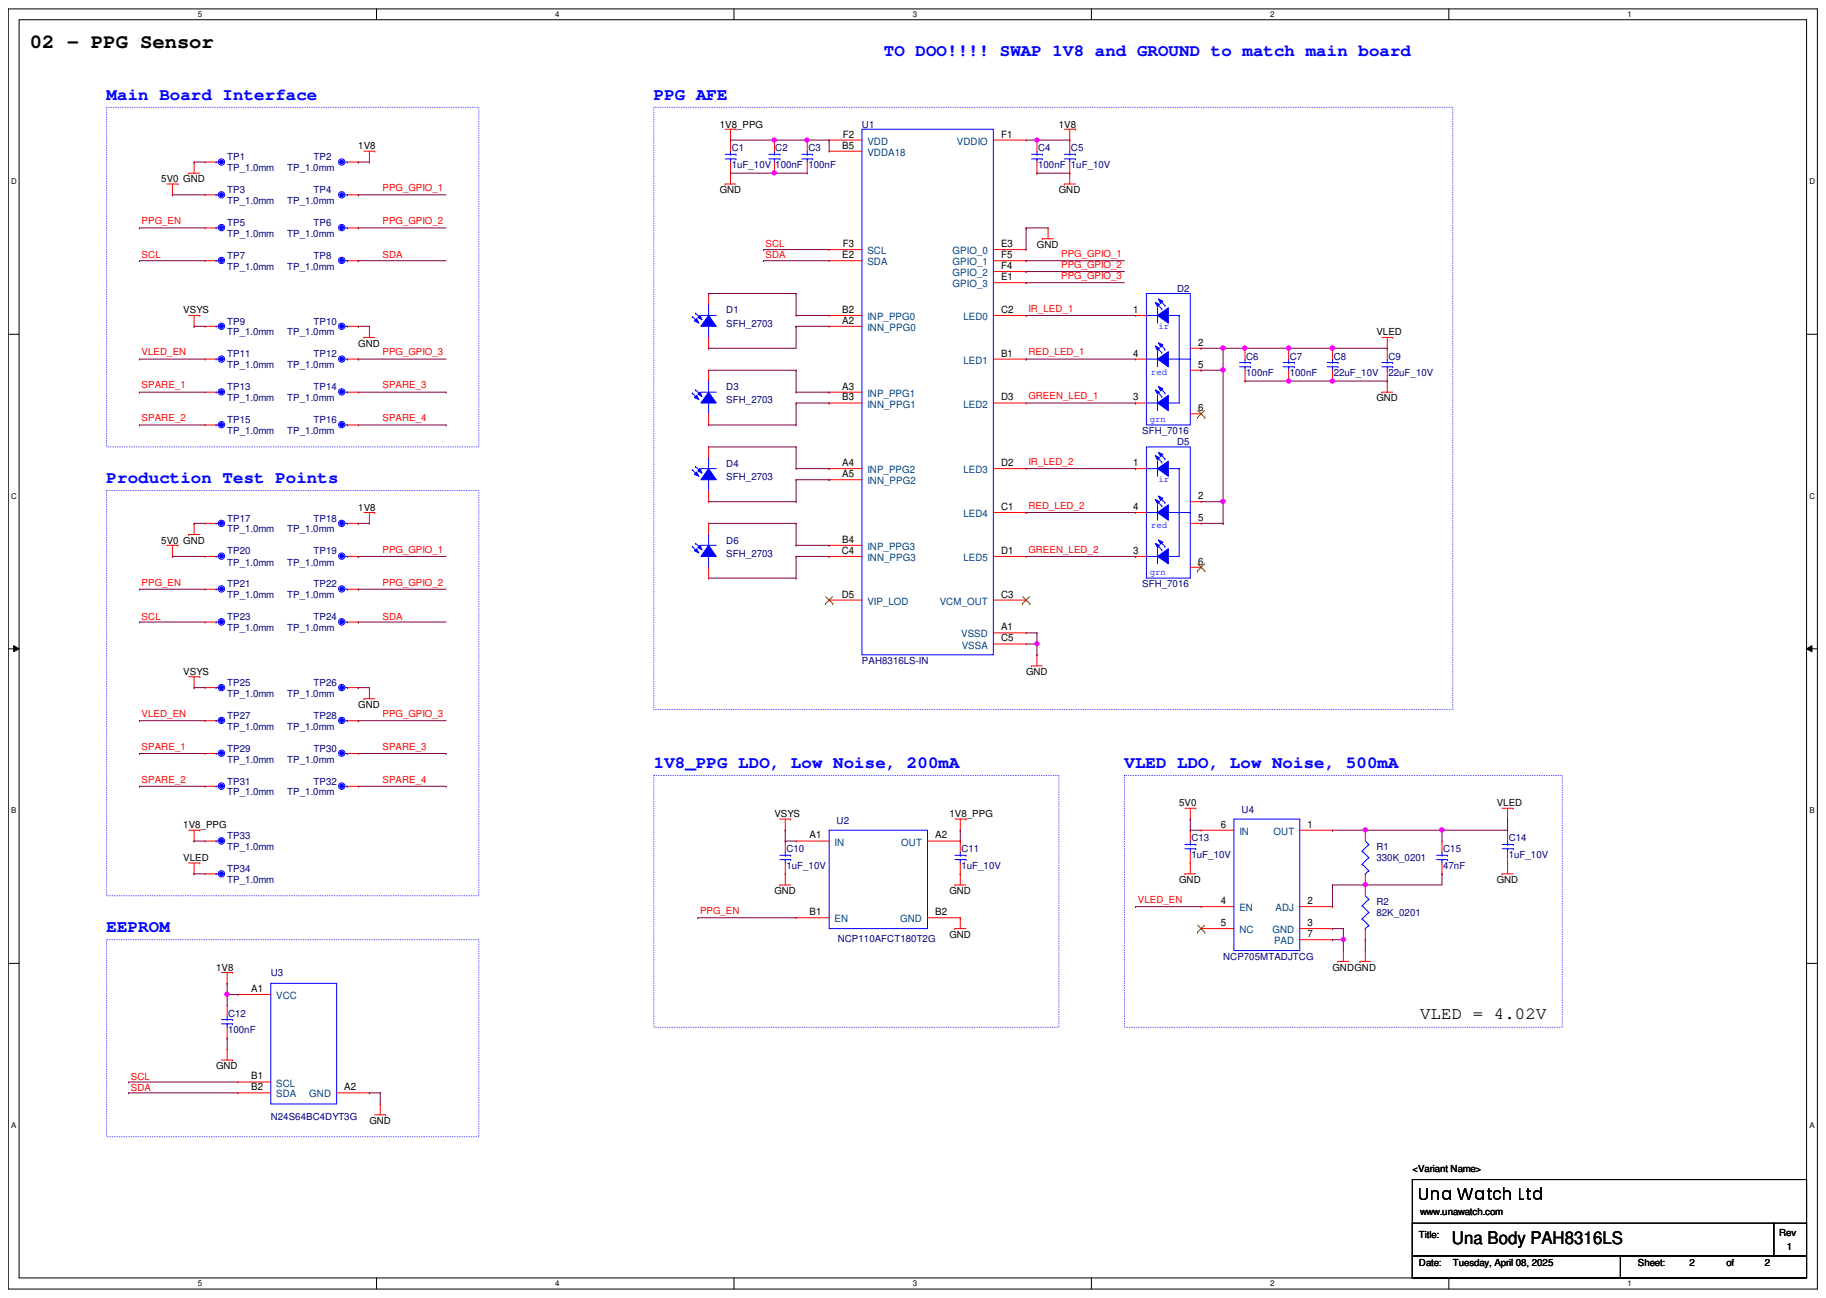
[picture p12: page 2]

TO DOO!!!! SWAP 1V8 and GROUND to match main board

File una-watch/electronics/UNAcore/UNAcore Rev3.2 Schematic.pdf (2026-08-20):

# 01 - Summary

Usage: | Main PCB for UNA Watch

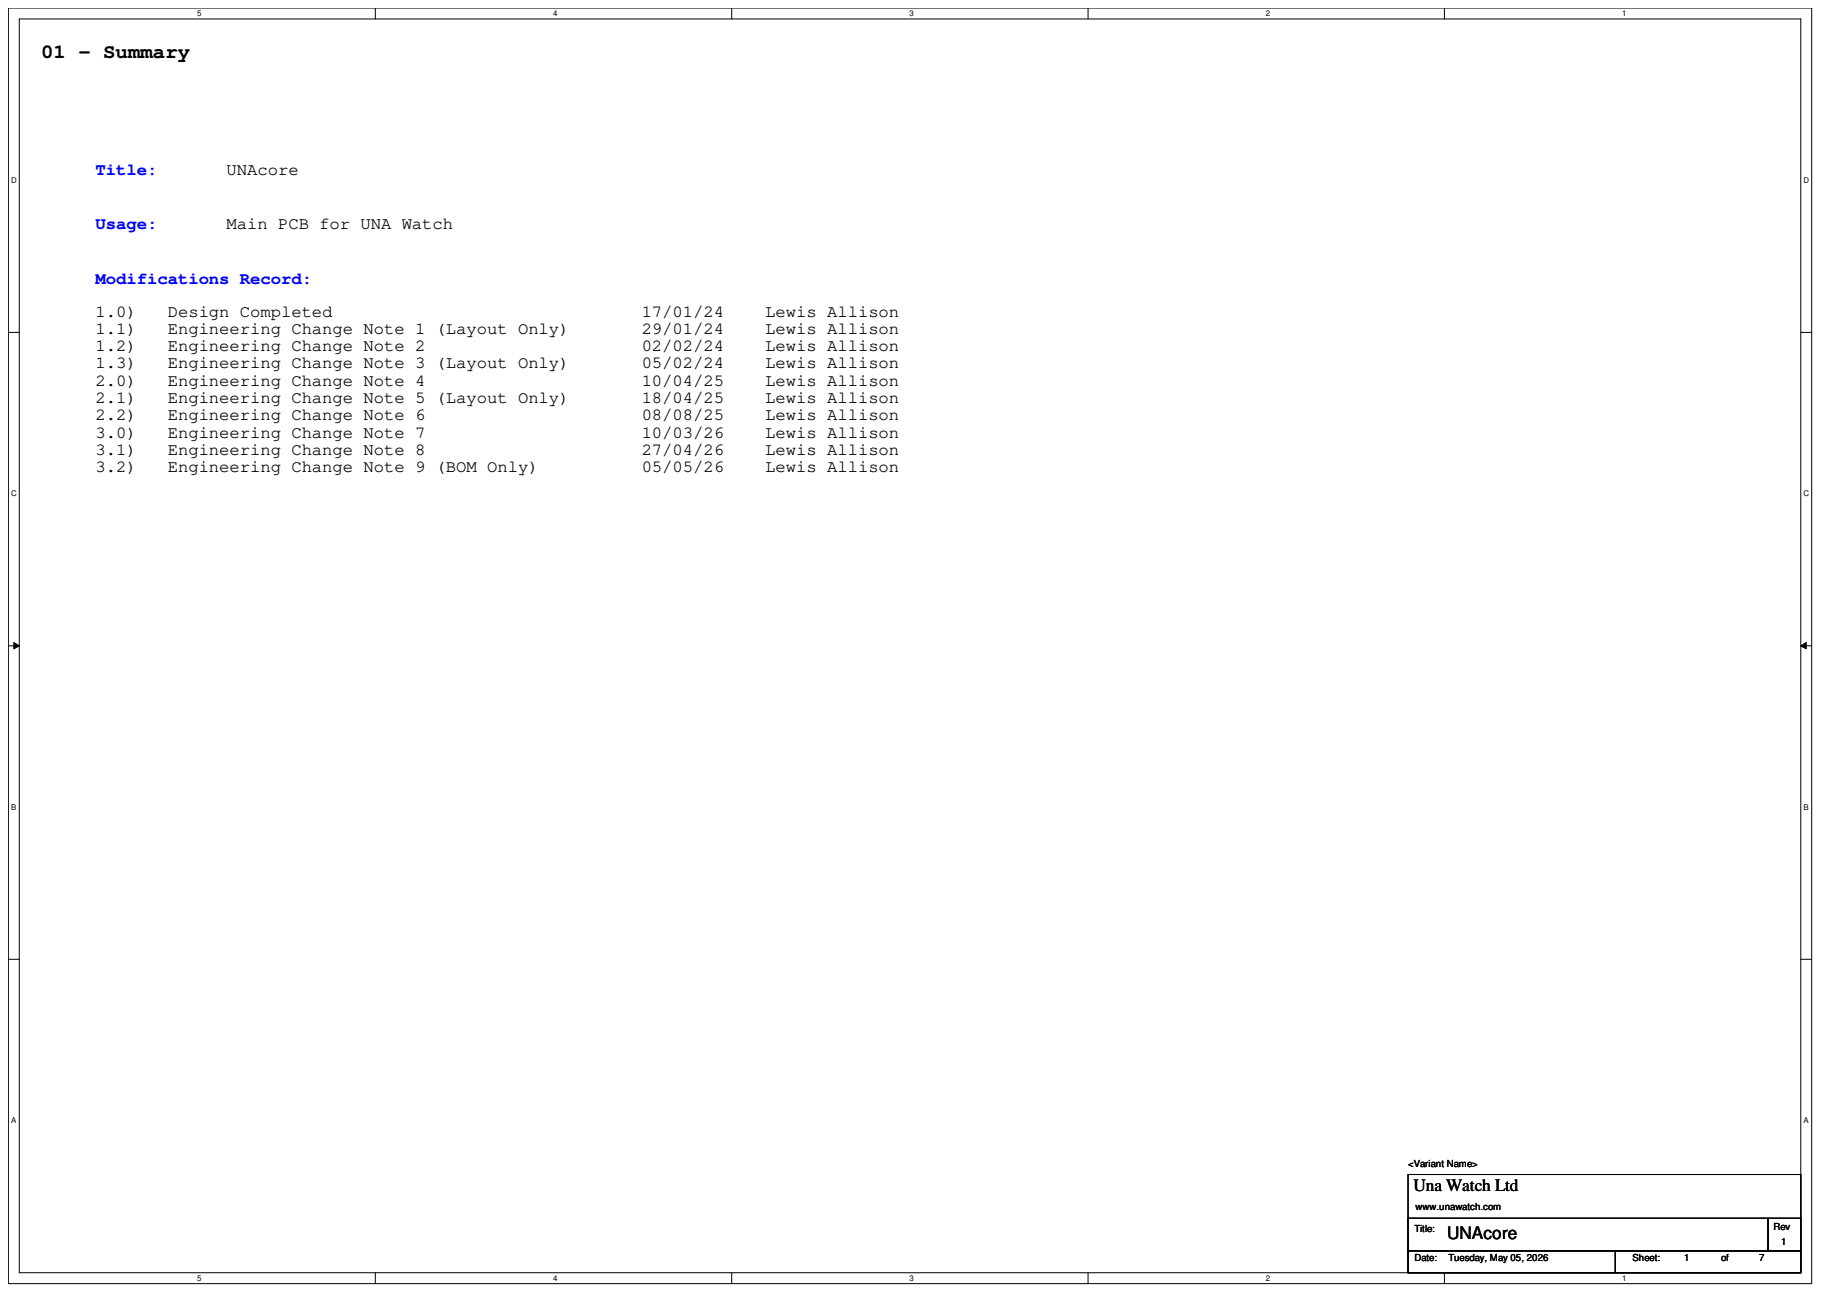
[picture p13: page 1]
Modifications Record:; Title:; UNAcore; Design Completed; Lewis Allison; Engineering Change Note 1 (Layout Only); Engineering Change Note 2; Engineering Change Note 3 (Layout Only); Engineering Change Note 4; Engineering Change Note 5 (Layout Only); Engineering Change Note 6; Engineering Change Note 7; Engineering Change Note 8; Engineering Change Note 9 (BOM Only); Rev; Date:; Sheet:; 7Tuesday, May 05, 2026

<Variant Name>
Una Watch Ltd

www.unawatch.com

# 02 - MCU

## 32-bit Cortex-M33 MCU

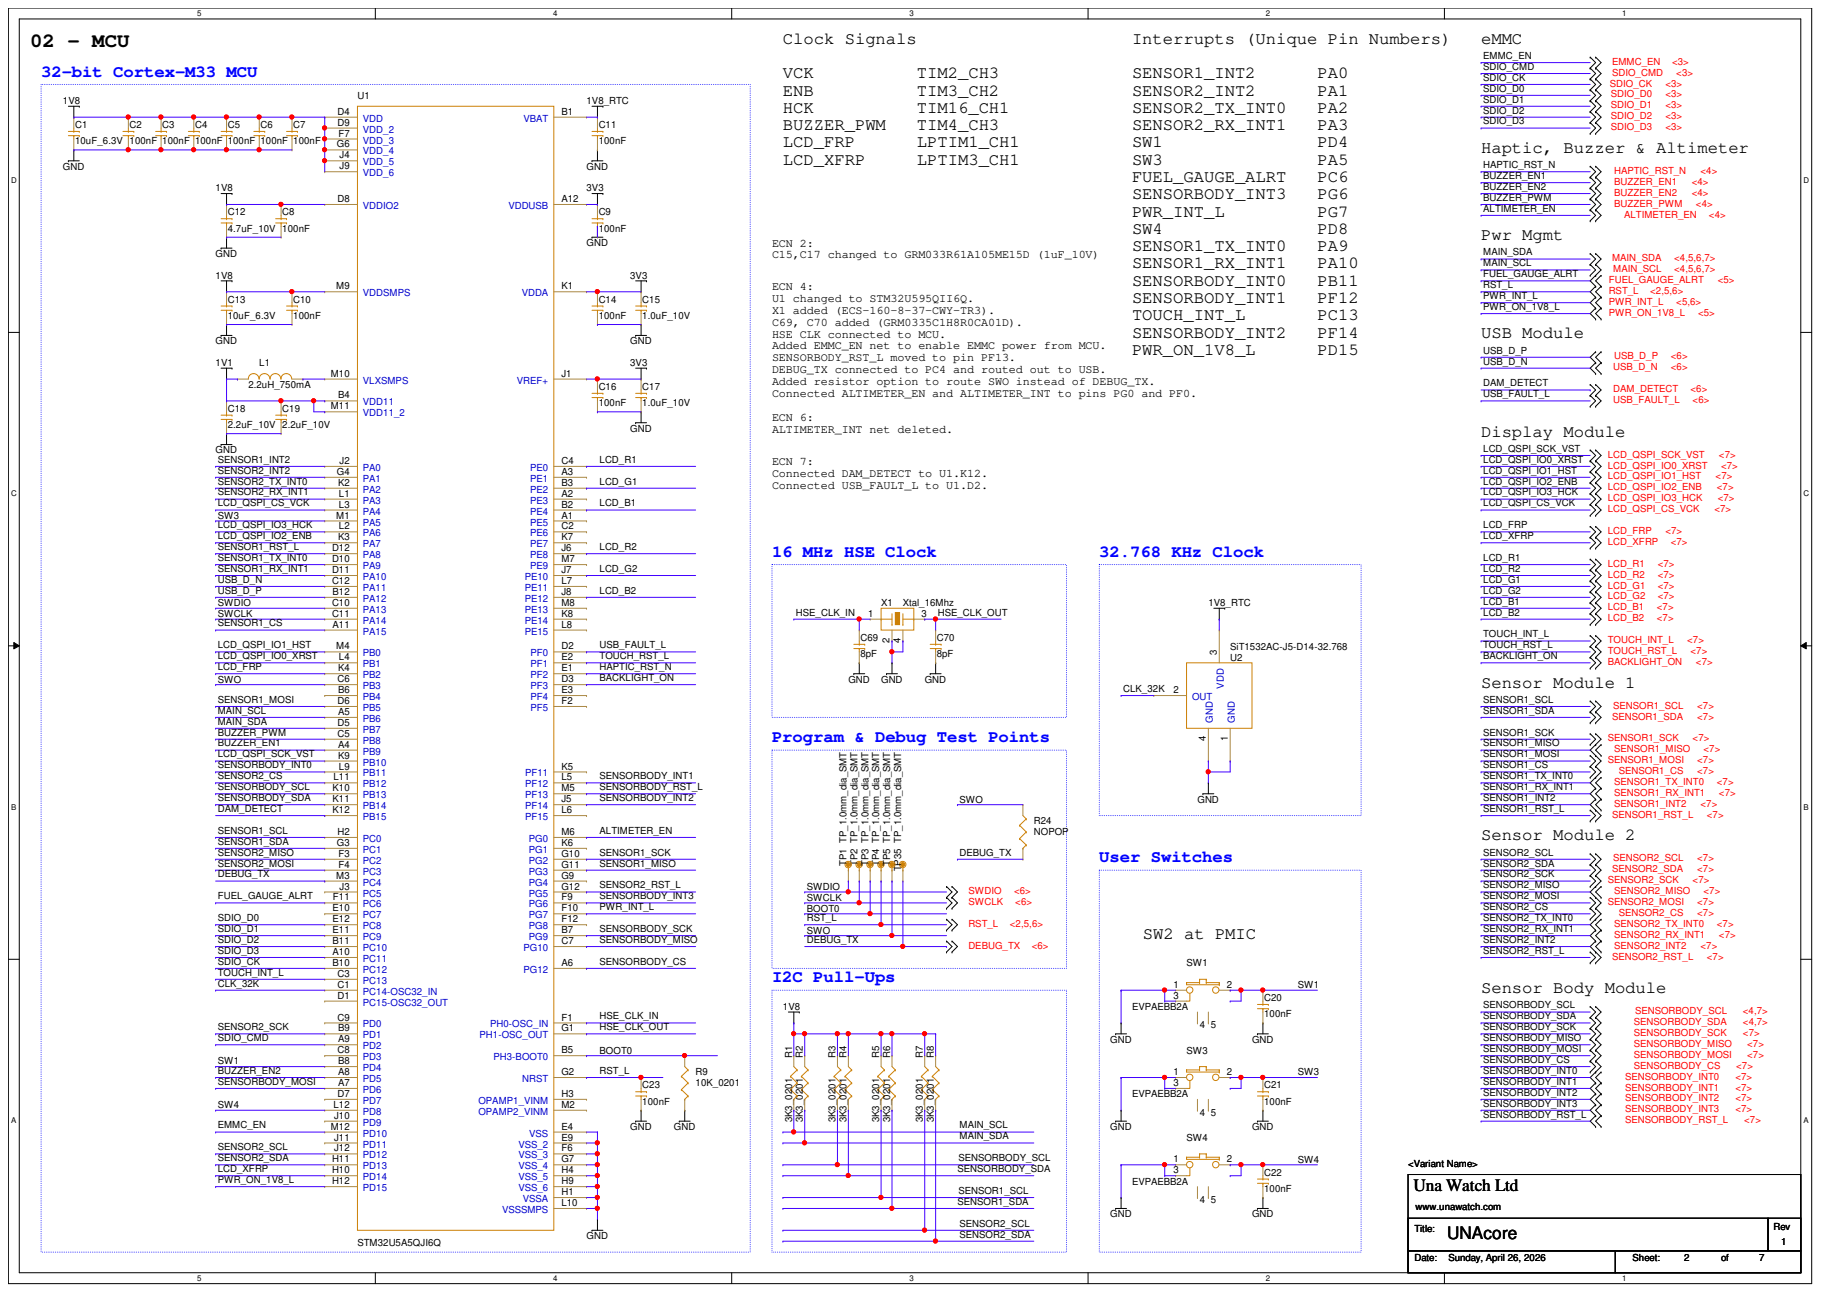
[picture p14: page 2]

Interrupts (Unique Pin Numbers)

ECN 4:
U1 changed to STM32U595QII6Q.
X1 added (ECS-160-8-37-CWY-TR3).
C69, C70 added (GRM0335C1H8R0CA01D).
HSE CLK connected to MCU.
Added EMMC_EN net to enable EMMC power from MCU.
SENSORBODY_RST_L moved to pin PF13.
DEBUG_TX connected to PC4 and routed out to USB.
Added resistor option to route SWO instead of DEBUG_TX.
Connected ALTIMETER_EN and ALTIMETER_INT to pins PG0 and PF0.

Program & Debug Test Points

# 03 - eMMC

## 4GB eMMC

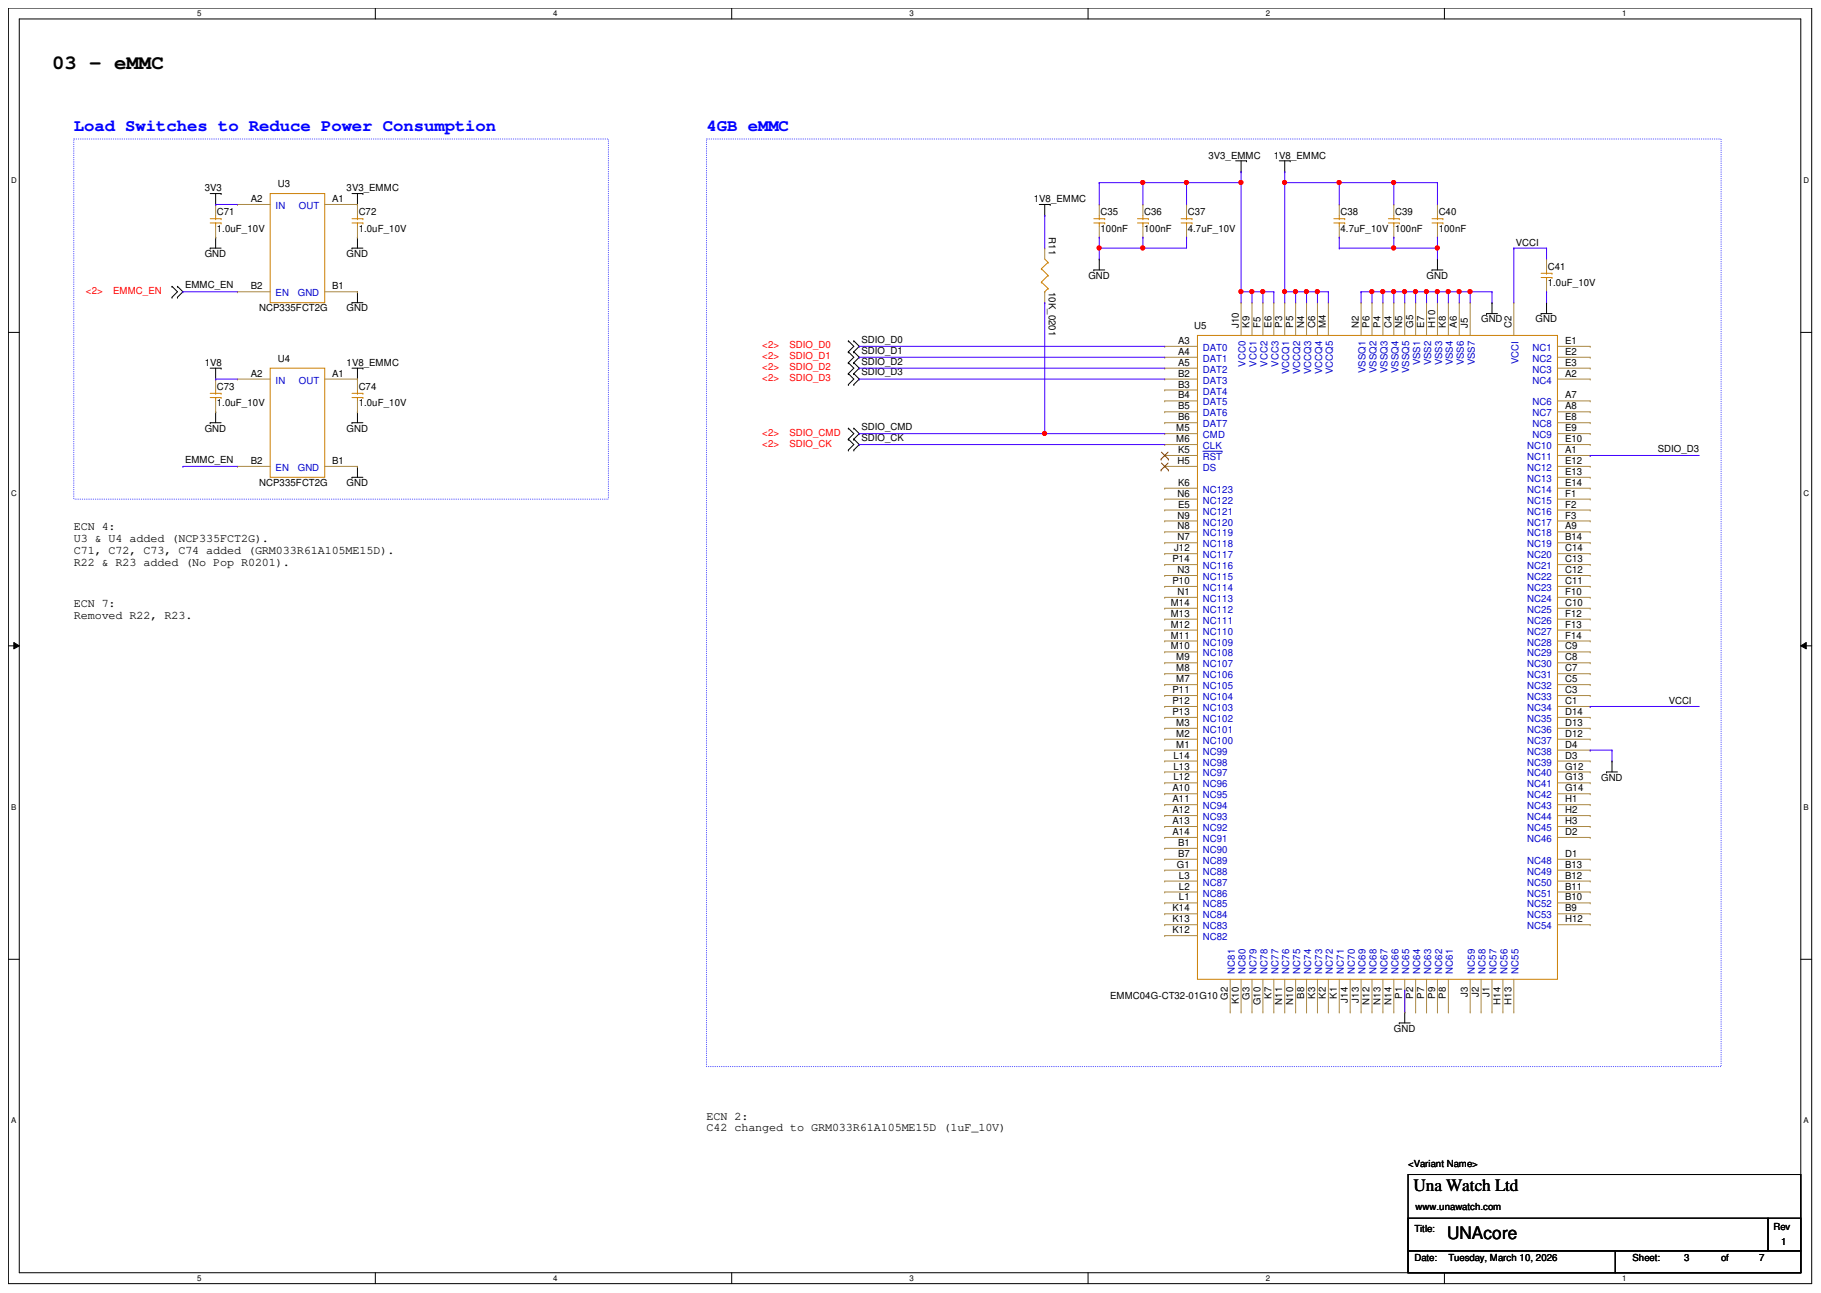
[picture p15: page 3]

Load Switches to Reduce Power Consumption

# 04 - Haptic, Buzzer and Altimeter

Vibration Motor Driver and ERM Motor | Piezo Sounder Driver

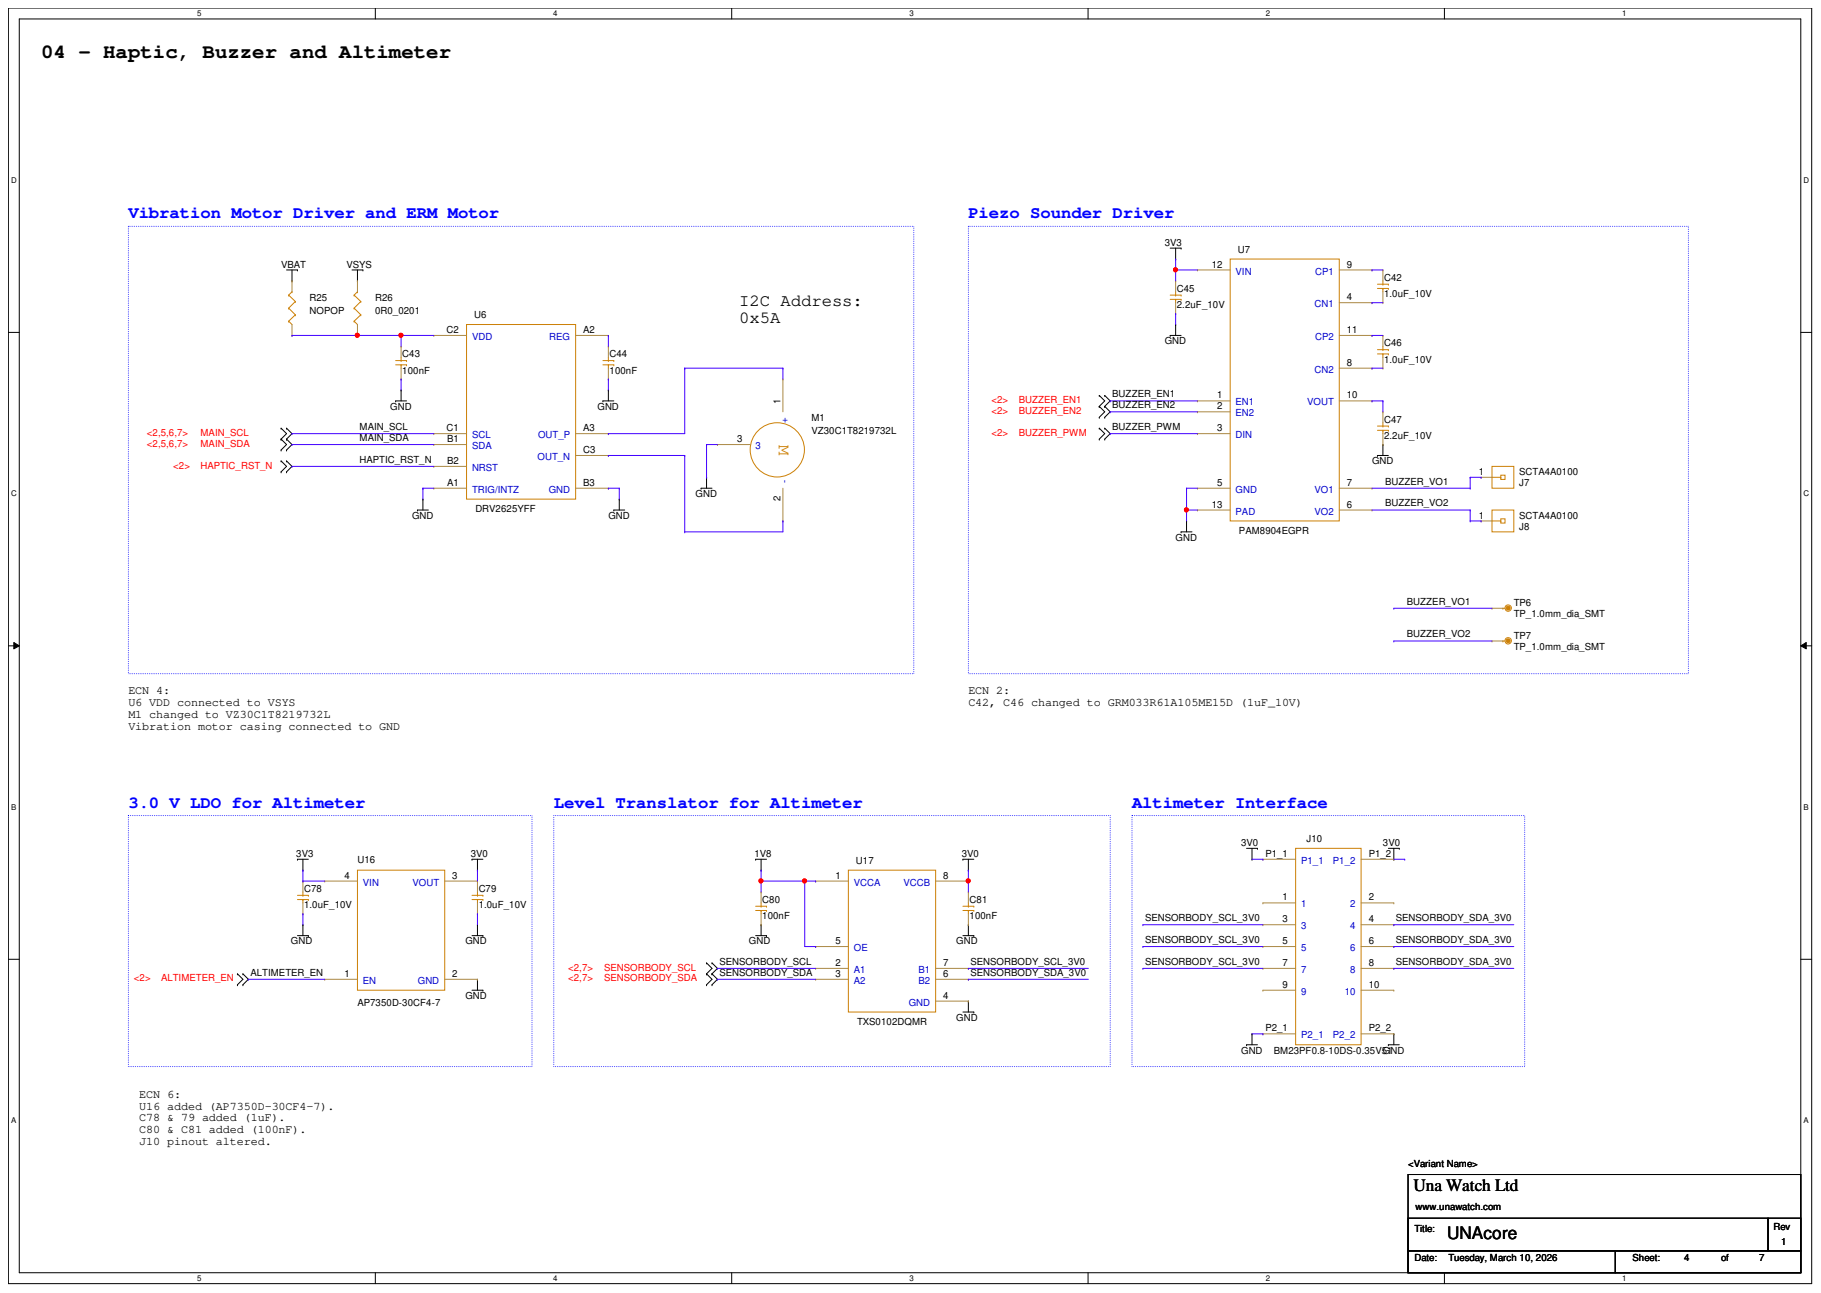
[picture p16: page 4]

ECN 4:
U6 VDD connected to VSYS
M1 changed to VZ30C1T8219732L
Vibration motor casing connected to GND

05 - PMIC | PMIC

# I2C Address:

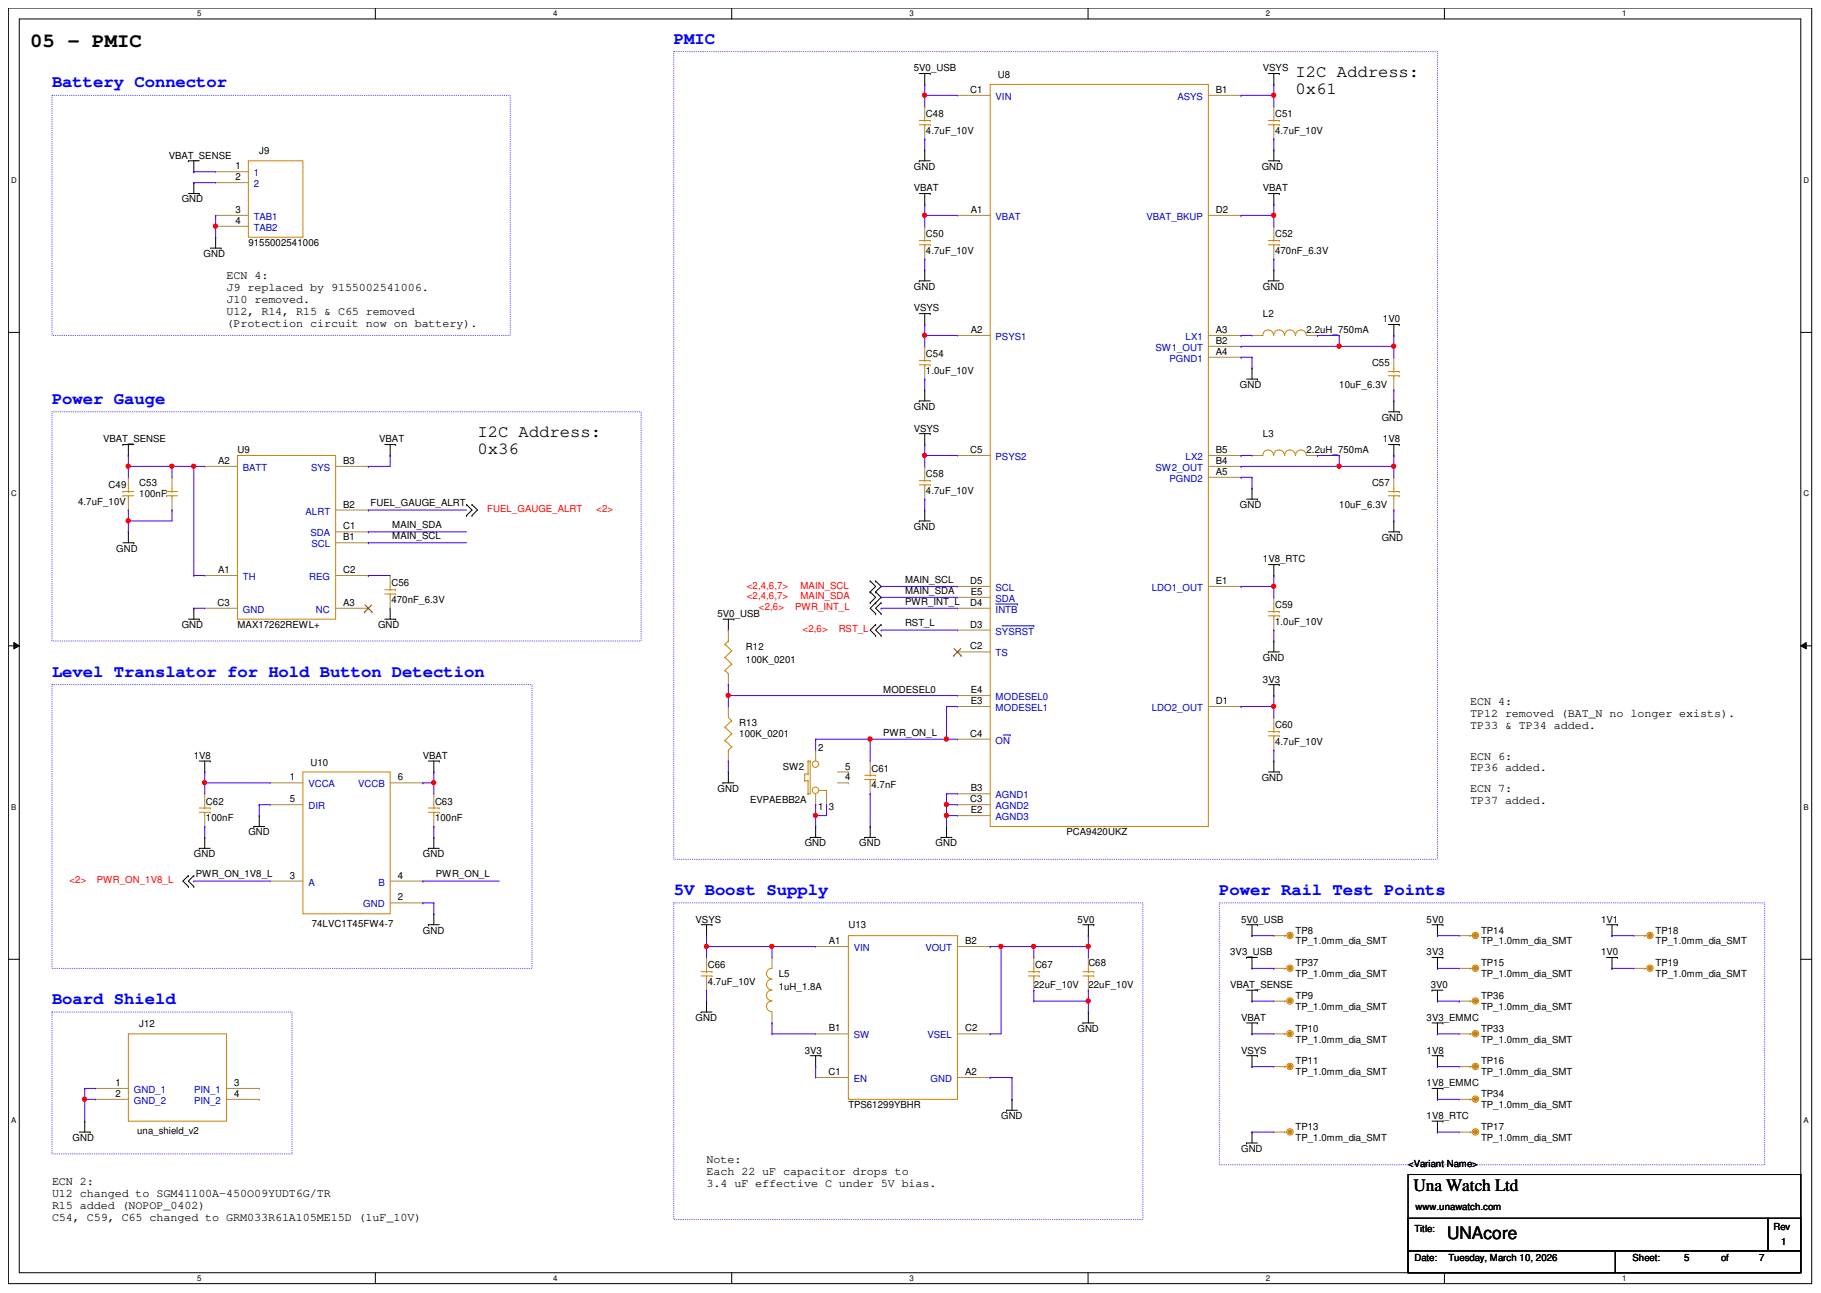
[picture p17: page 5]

ECN 4:
J9 replaced by 9155002541006.
J10 removed.
U12, R14, R15 & C65 removed
(Protection circuit now on battery).

Level Translator for Hold Button Detection

TP12 removed (BAT_N no longer exists).
TP33 & TP34 added.

Power Rail Test Points

Note:
Each 22 uF capacitor drops to
3.4 uF effective C under 5V bias.

# 06 - USB

## USB-C IPX8 Connector

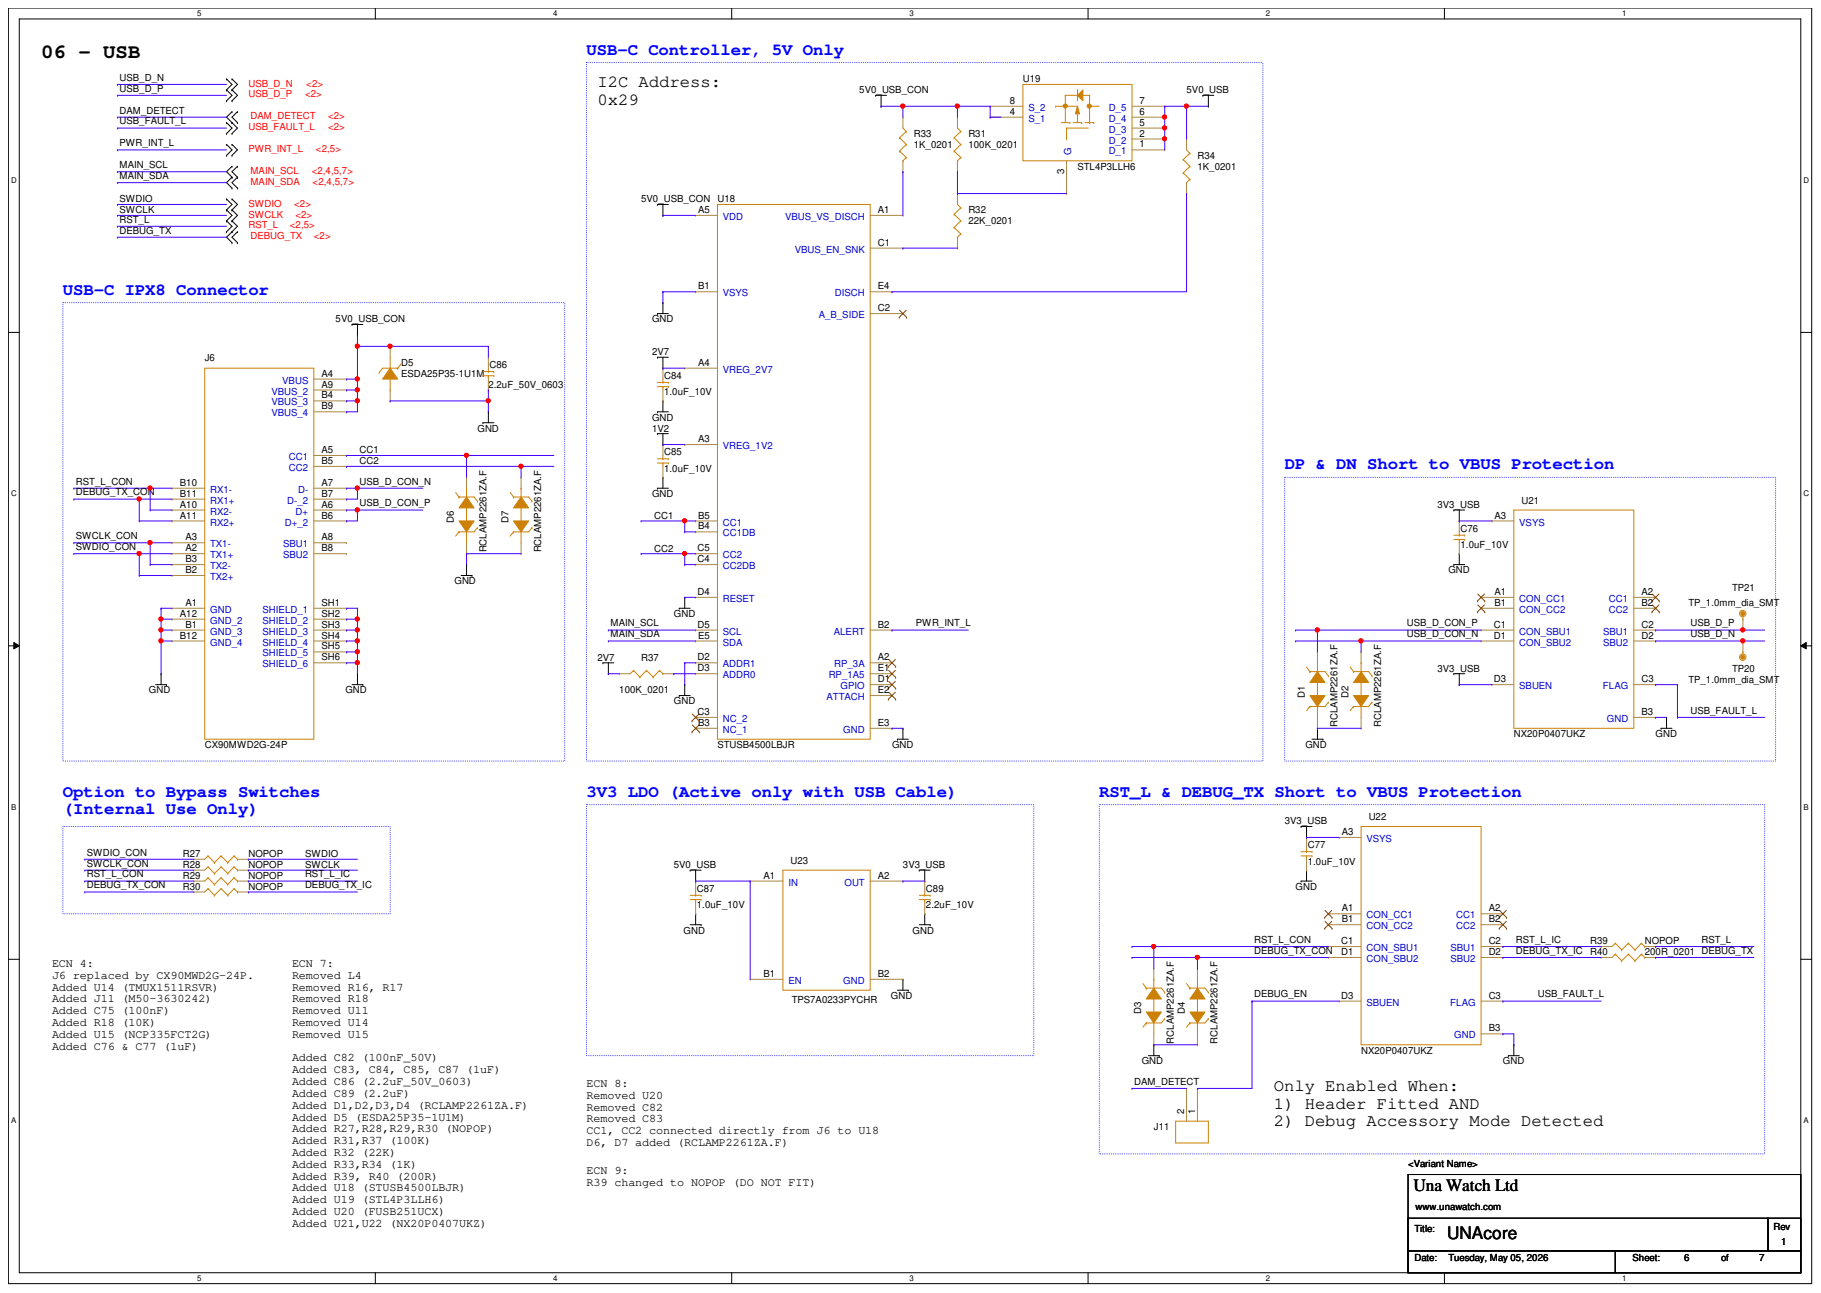
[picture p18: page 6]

DP & DN Short to VBUS Protection

Option to Bypass Switches
(Internal Use Only)

3V3 LDO (Active only with USB Cable)

RST_L & DEBUG_TX Short to VBUS Protection

Only Enabled When:
1) Header Fitted AND
2) Debug Accessory Mode Detected

ECN 9:
R39 changed to NOPOP (DO NOT FIT)

# 06 - Connectors to Modules

## Sensor 1 Module Interface


Body Sensor Module Interface

ECN 4:
Connected VSYS to J5 instead of 1V8.

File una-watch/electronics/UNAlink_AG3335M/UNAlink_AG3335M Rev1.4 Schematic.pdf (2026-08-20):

# 01 - Summary

Usage: | Link Module for Una Watch with AG3335M GNSS Receiver

Modifications Record:; Title:; UNAlink AG3335M; Design Completed; Lewis Allison; Engineering Change Note 1; Engineering Change Note 2 (BOM Only); Engineering Change Note 3; Engineering Change Note 4 (BOM Only); Rev; Date:; Sheet:; 5Tuesday, May 05, 2026

<Variant Name>
Una Watch Ltd

www.unawatch.com

# 02 - Main Board Interface

## Main Board Interface


# 03 - GNSS

## GNSS Power


ECN 1:
U2 pins A9, F8 & E8 connected to GND.
C11, C17 removed.
VDD_RF_IN and VCCK connected to 0V8.
R12 added.
C42 added.

ECN 3:
R1 removed.
R2 removed, TESTMODE connected to GND.

Connected G1 pin 1 to GND.

RTS, CTS removed.
WAKE_GNSS_TO_HOST, WAKE_HOST_TO_GNSS added.
R5 removed, FSOURCE_D connected to GND.
TXD_DEBUG and TP16 added.

# 04 - GNSS RF Front End

## GNSS Front-End


# 05 - IMU & Magnetometer

## IMU
